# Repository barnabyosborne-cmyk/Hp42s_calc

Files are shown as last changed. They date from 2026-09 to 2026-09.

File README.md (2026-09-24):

# HP-42S clone — Plus42 on an ESP32-S3

An HP-42S-shaped calculator: e-paper display, LiPo cell, USB-C and BLE, a
custom keypad PCB with metal dome switches, a resin-printed case, running
[Plus42](https://thomasokken.com/plus42/) on an ESP32-S3.

Case dimensions follow the original HP-42S as closely as the parts allow:
**148 × 80 × 15 mm**.

## What is in here

| Path | What it is |
|---|---|
| `elec/src/*.ato` | The wiring, as [atopile](https://atopile.io) source. Compiles to a netlist. |
| `elec/footprints/hp42s.pretty/` | The footprints KiCad does not ship, generated by the two scripts in `tools/`. |
| `elec/layout/` | The KiCad project. Placement and routing live here. |
| `tools/gen_dome_footprints.py` | Parametric generator for the metal dome sites. |
| `tools/gen_ic_footprints.py` | The same for the regulator, the IR emitter, the status LED, the ESD array, the USB-C receptacle and the recovery buttons. |
| `docs/connections.md` | The connection table in prose, with the reasoning. |
| `docs/keypad-geometry.md` | The measured key grid, and the clearances that follow. |
| `docs/display-mounting.md` | The panel's tail and off-centre image, and where the cell can go. |
| `docs/front-face.md` | The etched metal plate, the window, and an edge-lit frontlight. |
| `docs/before-layout.md` | **What is still open, and whether it stops you starting.** |
| `docs/board-thickness.md` | Why the board is 1.6 mm, and flex under the keyboard. |
| `docs/layout-walkthrough.md` | **The layout, step by step.** Written for a first PCB. |
| `docs/pcb-process.md` | The map from netlist to boards in your hand. |
| `docs/kicad-setup.md` | Why the pin numbers are what they are. |
| `docs/breadboard.md` | What a XIAO ESP32-S3 and a spare Waveshare panel can and cannot prove. |
| `firmware/` | The Plus42 port. Not started. |
| `hardware/` | Case and keycap files. Barnaby's own CAD. |

## Building the netlist

```
pip install atopile        # 0.2.69 at time of writing
ato --non-interactive build
```

The flag goes before `build`, not after.

Output lands in `build/`: `default.net` (KiCad netlist), `default.csv` (BOM),
and a designator map. atopile does the wiring and the netlist; it does **not**
place or route. Layout stays in KiCad.

## Headline choices

- **MCU** — ESP32-S3-MINI-1-N8. The S3 over the C3/C6 because only the S3 has
  full USB OTG, which is what allows drag-and-drop file transfer as a mass
  storage device. The `-N8` specifically: it has no PSRAM, and octal PSRAM
  would eat GPIO33–37, where the panel interface lives.
- **Display** — Good Display GDEY0266T90, 2.66", 296 × 152 px in a 71.82 ×
  36.30 mm outline. Plus42 character cells are 6 × 8 px, rendered **2× across
  and 3× down**, giving **24 columns × 6 rows** at very close to the original
  42S's character size. The obvious 2.9" panel is 79.0 mm wide and will not
  fit an 80 mm shell. See `docs/character-size.md` for why the scaling is not
  square.
- **Power** — BQ25185 charger with power path → TPS63900 buck-boost to 3.3 V →
  MAX17048 fuel gauge. The buck-boost is mandatory: the panel's VCI cannot
  take 4.2 V.
- **Keypad** — 37 keys, 6 columns × 7 rows, no diodes. Columns sit on
  RTC-capable GPIOs and wake the chip from deep sleep via `ext1`, so there is
  no scanner IC and no standing current. The physical grid is measured off a
  real 42S and is not uniform: 12.5 mm columns on the function rows, 15 mm
  across the numeric block.
- **On and off are keys, not a switch.** `EXIT/ON` wakes it and shift-`EXIT`
  sleeps it, the way a real 42S works. There is no power slider: the 3.3 V rail
  is always up and "off" is deep sleep at about 21 µA. Driving row 6 alone and
  arming `ext1` on column 0 alone makes `EXIT/ON` the only key that can wake it.
  `docs/power-control.md`.
- **Single-sided assembly.** Every part the fab house solders is on the back of
  the board. The front carries the panel, the 38 dome sites and the frontlight
  sliver's lands, all fitted afterwards. `docs/top-edge.md`.
- **Battery life** — roughly **15 months** on the 1600 mAh cell that fits, at
  2 h/day and 1500 keystrokes. About 33 hours of continuous execution. The cell
  is 6 × 45 × 55 mm, in board X 14–69 and Y 13–58 on the back.

## What is not settled

- **The panel's 47 µH inductor.** Named (Sumida CDRH2D18) but still on a
  stand-in land pattern, because the drawing has not turned up.

## Licence

The Plus42 firmware is GPLv2, and that carries over: anyone given or sold a
unit has to be able to get the source. Worth deciding on before the firmware
lands here.

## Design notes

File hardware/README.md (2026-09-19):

# Hardware — case and keycaps

Barnaby's own CAD. Nothing generated here.

Constraints the electronics impose:

- Case **148 × 80 × 15 mm**, board about **144 × 76 mm**, 4 layer.
- Face budget, from Barnaby's measurements of a real 42S rather than a
  reconstruction: the keyboard area is **70 × 78 mm**, its datum 5 mm in from
  the left and 9 mm up from the bottom. That leaves **61 mm** above it for the
  bezel and display, and a **9 mm chin** below.
- Key pitch: rows **12.0 mm** throughout; columns **12.5 mm** on rows 1–3 and
  **15.0 mm** on the numeric block of rows 4–7, with the left column staying
  on the 8.75 mm centre. Full table in `docs/keypad-geometry.md`.
- Keycaps 6.0 mm tall: 7.5 mm wide on rows 1–3 and in the left column,
  10 mm wide on the numeric block, and ENTER 20 mm wide.
- Keycap actuator must be **≤ 25 % of dome diameter**, centred. That is a
  Snaptron rule and it is why the centre pad in the footprint is small.
- Battery bay behind the keyboard: one clean **50 × 60 mm** rectangle, 5 mm
  deep, ≥ 15 mm clear of the module antenna.
- Panel mounts on the front of the board; its tail folds through a slot to a
  connector on the back, so the connector height stays out of the front stack.

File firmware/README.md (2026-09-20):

# Firmware — porting Plus42

The **board layer and the Plus42 core both build for the ESP32-S3.** Plus42
1.3.15 (Thomas Okken, GPLv2) is vendored in `components/plus42core/`, its
decimal arithmetic comes from Intel's BID library in `components/libbid/`, and
`main/shell.cc` is the platform layer that joins them to the board. What is
**not** done yet is the rest of the shell: keys are not yet fed to the core,
the annunciator strip is a stub, and nothing saves state. The display blitter
is written -- it scales 2x across and 3x down into the 275-pixel strip the
case aperture leaves visible, giving 23 columns by 6 rows -- but it has never
driven real glass.

## What is here

| File | What it does |
|---|---|
| `main/board.h` | Every pin number, in one place. The only file that changes for a different board. |
| `main/epd.c` | SSD1680 driver for the GDEY0266T90: init, full update, partial update, deep sleep. Landscape 296 x 152. |
| `main/keypad.c` | 6 x 7 diodeless scan, debounce, and `ext1` wake on any column going low. |
| `main/shell.cc` | The 22 shell functions Plus42 asks the platform for. Real: the display blitter, with 2x/3x scaling into the visible window, milliseconds, random seed, log. Stubbed: beeper, printer, clock, power-down. |
| `main/main.c` | Bring-up app. Draws a test pattern, starts the core, echoes key presses, deep-sleeps after 10 s idle. |
| `components/plus42core/` | Plus42's portable core, unmodified, plus a CMakeLists. |
| `components/libbid/` | Intel's decimal library. Sources are laid out by `vendor/setup.sh`, not committed. |

## Building

```
cd firmware
./vendor/setup.sh
. $IDF_PATH/export.sh
idf.py set-target esp32s3
idf.py build
idf.py -p /dev/ttyACM0 flash monitor
```

Built against ESP-IDF v5.5 on 2026-09-19.

## What it costs

Measured, at `-Os`, with the whole core linked in:

| | Flash | RAM |
|---|---|---|
| Intel decimal library | 2.20 MB (2.06 MB of it lookup tables) | 34 KB |
| Plus42 core | 414 KB | 6.7 KB |
| Board layer | 3 KB | 11 KB |
| **Whole image** | **2.85 MB** | **113 KB of 334 KB** |

So the `-N8` module's 8 MB of flash is comfortable but not generous: the app
gets a 4 MB partition (`partitions.csv`), leaving 3 MB of FAT for programs and
state. 221 KB of RAM is left for Plus42's heap, which is where user programs,
variables and the stack live.

**The decimal tables are the whole story on flash.** Free42 and Plus42 also
build in a "binary" flavour that uses the hardware double instead, which would
drop about 2 MB. It would also stop the calculator rounding the way a real 42S
rounds, so it is not on the table unless flash becomes the binding constraint.

## Three things that had to be worked out

1. **Exceptions.** The core throws in three places (`core_equations.cc`,
   `core_display.cc`, `core_commands9.cc`), so `CONFIG_COMPILER_CXX_EXCEPTIONS`
   has to be on. That costs 39 KB of unwind tables.
2. **`fexcept_t`.** Intel's header defines it as `unsigned short` unless a
   `fenv.h` guard macro is already set, while newlib's is `unsigned long`; the
   two collide. Both components are compiled with `-include fenv.h` so
   newlib's definition wins everywhere.
3. **`shell_always_on()` and `shell_alpha_keyboard_enabled()`** look like
   shell functions but are not: the core defines the first itself off Android
   and iOS, and `shell.h` macro-defines the second. Supplying either is a
   link error.

## The shell API

About 22 functions the platform has to supply. The ones that carry real work:

- `shell_blitter` — the whole display. **Must not assume a fixed size.**
  Plus42 resizes the display at runtime (`ROW±`, `COL±`, `SETDS`, `WIDTH`,
  `HEIGHT` in the DISP menu), 2–99 rows and 22–999 columns. Cells are 6 × 8 px.
  It also scales **anisotropically**: 2× across, 3× down, so one logical pixel
  becomes a 2 × 3 block of panel pixels. That is not something to tidy up later
  — it is what makes the characters the size of a real 42S's, because the
  original's pixels were 0.42 × 0.65 mm and ours are square. Two constants
  stand between 24 × 6 and 24 × 9. See `../docs/character-size.md`.
- `shell_annunciators` — the status strip.
- `shell_request_timeout3`, `shell_delay`, `shell_milliseconds` — timing.
- `shell_read_saved_state` / `shell_write_saved_state` — state to flash.
- `shell_get_mem`, `shell_low_battery`, `shell_powerdown`.
- `shell_print`, `shell_write`, `shell_read` — printing and file transfer.
- `shell_get_acceleration` / `_location` / `_heading` — stub these out.

## Power state machine

Three states, and two rules that matter more than the rest:

| State | Trigger | Cell current |
|---|---|---|
| Active | key or timer | ~24 mA |
| Idle | 0.5 s quiet, light sleep (SRAM retained) | ~265 µA |
| Off | 5 min quiet, deep sleep, state flushed to flash | ~25 µA |

1. **Never deep-sleep with a core timeout pending.** `core_keytimeout1` fires
   at 0.25 s and `core_keytimeout2` 2 s later; losing them loses keystrokes.
2. **Light-sleep through the panel refresh, waking on BUSY.** Spinning through
   a 400 ms partial update instead costs about 5× the energy per keystroke —
   0.70 µAh becomes 3.8 µAh. This one decision is the difference between
   15 months and 3.

A naive always-active port gets about 40 hours.

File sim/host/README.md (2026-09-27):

# Plus42 on a PC, drawing the real panel layout

`hp42s_host` is Plus42 and `firmware/main/shell.cc` compiled for this
computer, with a stand-in for `epd.c` that keeps the same framebuffer layout
and saves every panel update as a picture. It shows what the calculator draws
and where `shell_blitter` puts it on the 296 x 152 panel, including the columns
the case hides (grey) and the annunciator strip along the bottom.

It does not test the keypad scan or the SSD1680 protocol; that is what
`sim/wokwi/` is for. It costs no Wokwi minutes and runs in about a second.

```bash
bash ../../firmware/vendor/setup.sh      # once: lays out Intel's decimal library
make                                     # builds /tmp/hp42s-host/hp42s_host
make frames KEYS="2 ENTER 3 ADD SQRT"    # PNGs and sheet.png in /tmp/hp42s-host/frames
```

Keys are named by their legend in `host_main.cc` (`SHIFT`, `ENTER`, `ADD`,
`SIN`, `7`, ...) or given as core key numbers 1 to 37. It prints the X
register after each key, and the frame each key produced.

`frames.py` also reads a Wokwi run's output: `python3 frames.py run.log DIR`.

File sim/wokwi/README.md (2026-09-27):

# Wokwi simulation of the keypad and panel

Work in progress. What is here and what is left, so the next session can pick
it up.

## Done

- `chips/ssd1680.chip.c` -- a Wokwi custom chip for the SSD1680: SPI command
  and data decoding, RAM with address counters (0x11, 0x44/0x45, 0x4E/0x4F),
  BUSY timing (attributes `fullUpdateMs`, `partialUpdateMs`), hardware reset,
  deep sleep. Draws the black/white RAM landscape, 296 x 152. Warns on the
  console about commands sent while BUSY or during deep sleep, and RAM writes
  outside the window. **Builds** with `make -C chips` (clang wasm32 +
  wasi-libc + libclang-rt-18-dev-wasm32); not yet run in Wokwi.
- `firmware/` -- an ESP-IDF app that links `firmware/main/keypad.c` and
  `epd.c` unmodified and prints `key <n> <name>` / `up <n>` per keypress.
  Built with `HP42S_WOKWI`, which moves the panel's CS and DC to GPIO 40 and
  42 (`board.h`), since the DevKitC-1 does not bring out 33 and 34. **Not yet
  compiled.**

- `diagram.json` and `keypad.test.yaml` -- generated by `gen_diagram.py` from
  `s_map` in `keypad.c`, the pins in `board.h` and the legends in `sim_main.c`,
  so they cannot drift from the code. Re-run it after any of those change.
- `wokwi.toml` -- points wokwi-cli at the IDF build and the chip.

**2026-09-27: all 37 keys pass.** Each press prints the right key number and
legend, each release prints `up`, and the SSD1680 chip sees a clean full
update at start then one partial per key, with no command sent while BUSY.

## Running it

The IDF build cannot run inside `/mnt/project-files`, so copy the sources out:

    mkdir -p /tmp/sim && (cd /mnt/project-files/hp42s && tar cf - firmware/main sim) | tar xf - -C /tmp/sim
    cd /tmp/sim/sim/wokwi
    make -C chips                      # needs wasi-libc, libclang-rt-18-dev-wasm32
    (cd firmware && idf.py set-target esp32s3 build)
    wokwi-cli --timeout 240000 --scenario keypad.test.yaml .

`WOKWI_CLI_TOKEN` must be set. A full run takes about two minutes of
simulated panel refreshes. Set the chip's `debug` attribute to `"1"` in
`diagram.json` to log every SSD1680 command.

`wokwi-cli --screenshot-part` does not work on a custom chip ("Part does not
have a valid framebuffer"), so the panel image is only visible in the VS Code
extension or on wokwi.com.

## The calculator: `calc/`

`calc/` is Plus42 itself in the simulator: the real `shell.cc`, `keypad.c` and
`epd.c` under `calc/main/calc_main.c`, which prints `x <value>` after every key.
The panel chip in `calc/diagram.json` has `dumpFrames` on, so each frame it
shows is printed as `EPDFRAME` lines. `gen_diagram.py` writes both diagrams.

```bash
cd sim/wokwi/calc
idf.py set-target esp32s3 && idf.py build     # needs ../../../firmware/vendor/setup.sh run once
wokwi-cli --timeout 300000 --scenario add.test.yaml . | tee run.log
python3 ../../host/frames.py run.log frames/   # one PNG per frame, plus sheet.png
```

`add.test.yaml` presses 2 ENTER 3 + and waits for `x 5`. It builds (3.1 MB,
26% of the app partition free). It **has not run in Wokwi yet**: on
27 September 2026 the account's free monthly CI minutes were used up.

For what the screen looks like without spending Wokwi minutes, `sim/host/`
runs the same core and `shell.cc` on a PC.

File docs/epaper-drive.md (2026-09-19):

# Driving the e-paper panel

## Is there a driver board as well as the panel?

No, and yes.

There is no driver *board*. The controller for the GDEY0266T90 is an SSD1680
bonded directly to the panel's own glass, under the black strip at the edge of
the tail. You cannot buy it separately and you cannot design it out. When you
see a Good Display "driver board" — the DESPI-C02 and its relatives — you are
looking at a carrier that holds an FPC connector, a level shifter you do not
need, and the circuit below. It exists so that a panel can be plugged into an
Arduino. We are not plugging into an Arduino.

There is a driver *circuit*, and it was missing. It is now in
`elec/src/display.ato`. Eighteen parts.

## Why the panel needs anything at all

Electrophoretic ink moves when you push it with about +22 V and pull it with
about -20 V. The SSD1680 generates both rails itself, but it has no inductor
and no power switch on the glass, so it reaches outside for them through two
pins on the tail:

| pin | name | direction | what it does |
|-----|---|---|---|
| 2 | GDR | out | gate drive. The controller switches the external FET with this. |
| 3 | RESE | in | current sense. The voltage across R2 tells it how hard the inductor is being driven. |

The regulation loop is closed inside the panel. No MCU pin goes near it and
there is nothing for the firmware to do beyond the ordinary SSD1680 power-on
sequence. When the controller is asleep it stops driving GDR, the 1 M pulldown
holds the gate off, and the whole network draws nothing.

## The circuit

One switching node does both rails, which is why the parts count is so low.

    3V3 --+-- L1 47uH --+-------------------- D3 >|-- PREVGH --> VGH (pin 21)
          |             |                                |
         C4            Q1 drain                         C5
        4u7            Q1 gate <-- GDR (pin 2)          1u
          |            Q1 source --> RESE (pin 3)        |
         GND            |           |                   GND
                       R1 1M       R2 2R2
                        |           |
                       GND         GND

                        |
    switching node -----+-- C3 4u7 --+-- D2 >|-- GND
                                     |
                                     +-- |< D1 -- PREVGL --> VGL (pin 23)
                                                      |
                                                     C11 1u
                                                      |
                                                     GND

D3 is an ordinary boost diode and makes the positive rail. D1, D2 and C3 are a
charge pump hanging off the same node and make the negative one: D2 clamps the
pump node to ground on the up-swing, and on the down-swing the node goes below
ground and drags charge off VGL through D1.

Then ten capacitors, all 1 uF/25 V unless noted, all straight to ground:

| on | panel pin | Good Display ref |
|----|---|---|
| VCI (also 3V3) | 16 | C6 |
| VDD | 18 | C7 |
| VSH1 | 20 | C9 |
| VSH2 | 5 | C2 |
| VSL | 22 | C10 |
| VGH / PREVGH | 21 | C5 |
| VGL / PREVGL | 23 | C11 |
| VCOM | 24 | C12 |
| 3V3 input, 4.7 uF | — | C4 |
| pump, 4.7 uF | — | C3 |

The 25 V rating is not optional. VGH sits near +22 V and a 16 V part there
fails. Nor is it free: a 25 V X5R in 0603 loses most of its capacitance under
bias, which is why these are 0603 and not 0402 like everything else on the
board.

VDD (pin 18) is the controller's *own* internal regulator output. It takes a
capacitor and nothing else. Driving it kills the panel.

BS (pin 8) goes hard to ground, which selects 4-wire SPI. Pins 1, 4 and 19 are
no-connects; 6 and 7 are the touch I2C on the touch version of this glass and
ours has none.

## Where these numbers come from

Good Display's *GDEY0266T90 Specification*, revision 24.12.03, page 28. Not
from a generic SSD1680 application note: the inductor and the pump caps differ
between panels that share this controller, and a 2.13 inch reference circuit
will not drive this one properly.

Their spare-parts table, which is the actual purchasing spec:

    C1-C12   0603/0805, X5R/X7R, >= 25 V
    R1, R2   0603/0805, 1%, >= 0.05 W
    D1-D3    MBR0530: >= 30 V reverse, >= 500 mA, Vf <= 430 mV
    Q1       Si1304BDL / NX3008NBK: BVdss >= 30 V, Vgs(th) 0.9 V typ,
             Rds(on) <= 2.1 Ohm at Vgs = 2.5 V
    L1       Sumida CDRH2D18 or LDNP-470NC, 47 uH, Io = 500 mA max
    P1       24 pins, 0.5 mm pitch

**The MBR0530 is discontinued**, so D1-D3 are `1N5819HW`: 40 V, 1 A, same
SOD-123 outline, stocked everywhere. The 430 mV forward limit is Solomon's
number at their 500 mA sizing current; this pump draws tens of milliamps,
where a 1N5819HW sits well under it. The one thing to keep an eye on is
reverse leakage, because a charge pump holds its rail rather than being fed
one, and Schottky leakage is what drains VGH between refreshes. Nexperia's
PMEG family is the better class of part if a SOD-123 one can be sourced.

**Q1 is the Si1308EDL**, not either part Solomon name, and it beats the spec
they set: 30 V, Rds(on) 0.185 Ohm max at Vgs = 2.5 V against their 2.1 Ohm
limit (Vishay document 63399 rev C). Its package is **SOT-323 / SC-70**, not
the SC-75A this repo had it as.

Q1's low gate threshold is the reason it is not the 2N7002 used elsewhere on
this board: the panel drives that gate from its own 3.3 V logic, and a 2N7002
is only specified to turn on by 2.5 V.

## Layout notes

The switching node — L1, Q1's drain, C3 and D3's anode — is the only fast node
on the board other than the buck-boost. Keep that loop small and keep it away
from the panel's SPI, which runs alongside it into the same connector.

R2 carries the switched current, so it wants a short path to the ground pour,
and its 1% tolerance is real: the panel sets its peak inductor current from the
voltage across it.

L1 in an NR3015 body is 1.5 mm tall, which makes it the tallest part on the
board after the module and the cell.

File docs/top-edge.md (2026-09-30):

# The top edge

Five things come out of the 80 x 15 mm top face of the case, and all five are on
the **back** of the board:

| | part | why it is here |
|---|---|---|
| IR emitter | Vishay VSMB2943SLX01, 940 nm side-looking | the original 42S's IR window is on this edge |
| USB-C | GCT USB4105-GF-A | charging and file transfer |
| status LED | Dialight 599-0Q70-247F, red/green side-view | boot, error, nominal |
| BOOT | Alps SKRTLAE010, side push with guide bosses | recovery |
| RESET | Alps SKRTLAE010, side push with guide bosses | recovery |

**There used to be a sixth, a C&K JS102011SAQN power slider.** It went on
24 September 2026: a real HP-42S switches on with a key, and so does this one.
`docs/power-control.md` has the whole of that change. It freed board X 6 to 16
on this edge and nothing has claimed it.

## Why the back

Barnaby asked on 24 September 2026 to put them on the back, "more balanced for
the centering of them in the top panel". He is right, and the stack-up says by
how much.

`docs/front-face.md` sets the vertical budget: a 15 mm case with 1.2 mm shells
leaves 12.6 mm inside. Measured from the case's outer **front** surface, with
the light guide against the inside of the front shell:

| | from | to |
|---|---|---|
| front shell | 0.00 | 1.20 |
| light guide, 1.0 mm cast acrylic | 1.20 | 2.20 |
| air gap | 2.20 | 3.00 |
| adhesive | 3.00 | 3.20 |
| panel glass | 3.20 | 4.20 |
| **board, 1.6 mm** | **4.20** | **5.80** |
| cell, 6 mm | 5.80 | 11.80 |
| slack | 11.80 | 13.80 |
| back shell | 13.80 | 15.00 |

So the board's front face sits 4.20 mm inside the case and its back face 5.80.
The top wall's centreline is at 7.50. Each part's aperture is on the axis of
whatever comes out of it, and that axis is a fixed height above the face the part
is soldered to — measured off the vendor STEP models in
`elec/footprints/hp42s.3dshapes`:

| part | axis above its own face | on the FRONT | on the BACK | off centre, front / back |
|---|---|---|---|---|
| USB-C mouth | 1.28 | 2.92 | **7.08** | 4.58 / 0.42 |
| IR optical axis | 1.15 | 3.05 | **6.95** | 4.45 / 0.55 |
| tact plunger | 1.65 | 2.55 | **7.45** | 4.95 / 0.05 |
| status LED lens | 0.50 | 3.70 | **6.30** | 3.80 / 1.20 |

On the back all four apertures land within 1.2 mm of the wall's centreline, and
the two mechanical ones within half a millimetre. On the front they sat 4 to 5 mm
high in a 15 mm wall.

**And the USB-C one was not merely off centre, it did not fit.** With the
receptacle on the front, the top of its 2.56 mm shell is at 1.64 mm — which is
0.44 mm short of the front shell's inner face at 1.20. That is a 0.44 mm ledge of
resin over the cut-out, which is not a printable feature. Worse, the plug: a
Type-C plug's overmould is about 4.5 mm across, so centred on a mouth 2.92 mm
below the outer surface it would stand about half a millimetre **outside** the
case's front face. The receptacle could have been soldered; the cable could not
have been plugged in without slotting the front of the case.

On the back the same plug body spans 4.8 to 9.3 mm, with 3.6 mm of clearance to
the front shell and 4.5 mm to the back one.

### What it costs

**3.5 mm of battery bay, and then 1 mm of cell thickness.** Two steps, and the
second is the one Barnaby's case model has to absorb.

The bay was board Y 5 to 59, about 54 mm, and it took a 5 x 50 x 60 mm cell —
1600 mAh with a millimetre to spare. The five parts on the back reach as far in
as the USB-C's courtyard at Y 7.24, so the bay would start at Y 8.5: 50.5 mm,
which the same cell still fits, with nothing to spare.

Then Barnaby asked for every reflowed part on one side (below), which put the
nine parts that serve the top edge on the back as well. The deepest of those is
U1 at Y 11.66, so **the bay is now Y 13 to 58, 45 mm, X 14 to 69.**

A 6 x 45 x 55 mm cell is about 14,850 mm³ against the 505060's 15,000, so it is
**the same 1600 mAh one millimetre thicker**, and it was always the second of the
three fallbacks in `docs/display-mounting.md`. The 6 mm is already in the table
above: `docs/front-face.md` budgeted a 6 mm cell from the start and the deepest
arrangement still leaves 2.0 mm of slack. Nothing has to grow.

If a 6 mm cell in that footprint turns out to be hard to buy, the other two
fallbacks are unchanged and both still work: let the cell run past Y 58 into the
keyboard region, or accept about 1400 mAh in 5 x 48 x 55.

### What it gives back

**The USB-C's four through-hole shield fillets are on the FRONT now.** They used
to land in the battery bay at board Y 0 to 5, under the cell, which is why the
bay was 54 mm and not 57 — a pouch cell resting on four solder fillets is not a
risk worth taking, because the case is soft aluminium laminate and it grows over
its life. Those fillets now come through under the bezel, where nothing touches
them.

One thing to check against the case model: keep the frontlight's light guide
clear of board Y 0 to 5, or let it stop at the glass. There is 3.0 mm of air in
front of the board in the bezel band and a through-hole lead cut for a 1.6 mm
board stands well under that, but the guide is the only part that could foul it.

## Everything the fab house solders is on the back

Barnaby asked for this on 24 September 2026, to make the board a single-sided
assembly. It is the cheaper build: one stencil, one paste print, one reflow, no
glue and no second pass.

**The front now carries nothing that comes back from the fab already soldered.**
What is on the front is the panel, the 38 dome sites and the frontlight sliver's
two lands and ground point, all of which go on afterwards.

What moved with it, from the front at exactly the same x and y:

| | serves |
|---|---|
| U1, R1, R2, C1 | the USB-C: ESD array, CC pulldowns, VBUS bulk cap |
| Q2, R17, R18 | the IR emitter's driver |
| R19, R20 | the status LED's two ballast resistors |

They are all directly behind where they were, so every distance to the part it
serves is unchanged, and the USB pair no longer has to cross the board through
vias to reach its ESD array. `tools/check_placement.py` reports the whole board
clear at 1 mm courtyard to courtyard.

Turning a footprint over mirrors it in y, so pin 1 of U1 and of Q2 has moved from
one end of the body to the other. Neither matters — the ESD array's four channels
are interchangeable and the SOT-23 is a single transistor — and nothing is routed
yet.

**One thing still spoils the single-sided story, and it is worth a look now.**
This USB-C receptacle anchors with four through-hole shield legs. Every 16-pin
Type-C part does; they take the cable strain, which is why the case gets a lip
rather than the connector getting a different land pattern. But a through-hole
part is a second operation whichever side it protrudes from. A receptacle with
**SMD-only shell tabs** would make this board genuinely one-pass. The two
locating pegs and the Alps switches' guide bosses are non-plated holes and cost
nothing. `BT1` is already on its way from a through-hole JST PH to the SMD
`S2B-PH-SM4-TB`.

## Side actuation is the whole trick

An ordinary tact switch has its plunger on top, pointing out of the board's face.
It cannot reach a case edge. Both switches here are side-actuated: the plunger
comes out of the *end* of the body, in the plane of the board.

- **Reset and BOOT: Alps SKRTLAE010**, body 4.5 x 2.56 mm with the plunger
  **1.05 mm** proud of it (0.84 was the catalogue figure; Alps' own STEP model,
  checked 23 September 2026, has it reaching 2.261 mm from the origin),
  4.5 x 3.55 overall and 3.3 tall, with the guide bosses 0.5 below the board
  face. 1.6 N to operate and 0.2 mm of travel, so it is a deliberate press with
  a fingernail or a pen, not something a pocket does by accident. 100,000
  cycles, which for these two is forever.

  It is the `-LAE010`, the variant **with guide bosses**, so each one needs two
  0.9 mm non-plated holes in the board as well as its five pads, and a 2.0 x
  1.2 mm patch between the mounting pads that Alps marks as prohibited for
  copper. All three are in the footprint. The `-LBE010` is the same switch with
  no bosses and no holes if that ever becomes awkward.
- **USB-C: GCT USB4105-GF-A**, mouth flush with the board edge. Shell outside
  8.64 x 2.56 mm, body 8.94 wide x 7.35 deep, with four through-hole shell legs
  and two 0.65 mm locating pegs. KiCad's footprint is drawn from GCT's own
  document and marks the product edge on Dwgs.User at 3.675 mm from the origin,
  which is what the placement is set from — the same number the Same Sky UJ20 it
  replaced on 22 September 2026 used, so the case cut-out line did not move.

  **A Same Sky UJC-HP-G-5-SMT-TR was evaluated on 24 September 2026 and
  rejected: it is power-only.** It has six contacts — A5/B5 `CC`, A9/B9 `VBUS`,
  A12/B12 `GND` — and no `D+`/`D-` at all. That is a fine part for a charge-only
  product and it is a smaller one, 11.54 x 7.14 x 3.21 mm from its STEP model,
  but this board needs USB **data** twice over. Once because file transfer over
  USB is a headline feature, the thing you plug in to load a program. And once
  because the S3's own USB peripheral is the only flashing path that exists
  here: there is no USB-UART bridge on the board (see "Why a BOOT button as well
  as RESET" below), so with a power-only receptacle a bricked board could not be
  reflashed at all, by anyone, ever. Keep the USB4105-GF-A.

## Reset

A plain button from the module's `EN` to ground. It is a hardware reset of the
chip and does not go near the firmware, which is the only reason to have it — you
press it when the firmware has stopped working. With no power slider it is also
the only way to interrupt firmware that has hung: see `docs/power-control.md`.

The existing 10k and 1 uF on `EN` debounce it for free: the cap holds `EN` down
for about 10 ms after release, and Alps specifies the contact bounce at 10 ms
when new and 20 ms at end of life. Those are the same order, so the RC does not
swallow the bounce outright — what it does is turn a bounce train into one slow
ramp, because the cap cannot recharge through 10k faster than the contacts are
chattering. The chip sees one release. `BOOT` is the one that needs the software
debounce: 20 ms or more, from the same Alps number.

Recess it in the case. This is not a key. A reset button you can press while
holding the calculator is a reset button you will press while holding the
calculator.

## Why a BOOT button as well as RESET

Because it is the only recovery path, and without it the recovery path is a
screwdriver.

A dev board gets away without a BOOT button because its USB-UART bridge wiggles
`EN` and `IO0` from the host, which is how esptool puts the chip into download
mode on its own. This board has no bridge — the S3 drives USB itself. The moment
the firmware claims the USB OTG peripheral for mass storage, the USB-Serial/JTAG
path that esptool could otherwise reset through is no longer on those pins. And
if the firmware is broken enough not to enumerate at all, nothing on the host can
reach the chip by any route.

Hold BOOT, tap RESET, release BOOT, and the ROM bootloader comes up regardless of
what is in flash. Recess BOOT deeper than RESET; it is pressed roughly never, and
the two should not feel alike.

## The status LED

Dialight 599-0Q70-247F: two dice, red and yellow-green, sharing a **common
anode**, so a channel is driven LOW to light.

It is bi-colour, not RGB, and that is the right answer rather than a concession.
Red and green together read as amber, so two dice give three states, which is all
the indicator was ever asked for. A true RGB part would need a blue die, every
blue die is InGaN, and InGaN wants up to 3.9 V forward against this board's 3.3 V
rail. The 599's two AlGaInP dice run at 2.0 to 2.4 V with room to spare.
Barnaby's first pick, the -0Q40-, is yellow plus yellow-green, which no one can
tell apart through a diffused window; the -0Q70- is the same part with a red die
instead of the yellow.

Common anode does leave a weak pull-up on the two driving pins while they are
high impedance. That was a real objection when the plan was three channels on an
unverified part, and it is not one now: `IO16` and `IO39` are not strapping pins
— only `IO0`, `IO3`, `IO45` and `IO46` are — and the current through an unlit LED
is leakage rather than a divider. Dark at reset, through boot, and in deep sleep,
which is what matters: an indicator left on is milliamps against a 21 uA sleep
budget. Blink it during boot and on error, and leave it dark in normal use.

It costs two GPIOs rather than three. `IO16` was spare; `IO39` is one of the four
JTAG pins, which this board had already given up in practice — the USB pins go to
the OTG peripheral, and debugging runs over the UART0 test pads. **`IO40` goes
back to the free list**, and `docs/power-control.md` wants it: moving `LED_RED`
off `IO16` would free the S3's `XTAL_32K` pair for a real 32.768 kHz timebase.
1k on a 2.0 V die off 3.3 V is about 1.3 mA, plenty behind a case window.

**The lens is 1.0 mm tall and its axis sits 0.50 mm above the face it is
soldered to**, measured from Dialight's STEP model on 24 September 2026. This
file used to say "roughly 1.0 to 2.0 mm", which was a guess and was wrong. The
lens wants a diffused window rather than the clear one the IR needs.

## Placement

`tools/place_board.py` places all five, on the back. Y is depth from the board's
top edge, and each part is pushed out until its own pads stop it.

| part | x | y | courtyard across x | courtyard reaches | protrudes past the edge |
|---|---|---|---|---|---|
| IR emitter | 25.33 | 0.900 | 22.98 .. 27.68 | y = 2.34 | 0.73 mm |
| USB-C | 38.00 | 2.475 | 32.68 .. 43.32 | y = 7.23 | 1.70 mm |
| status LED | 50.57 | 1.050 | 48.32 .. 52.82 | y = 2.45 | 0.77 mm |
| BOOT | 60.65 | 1.800 | 57.82 .. 63.48 | y = 3.85 | 0.50 mm |
| RESET | 71.31 | 1.800 | 68.48 .. 74.14 | y = 3.85 | 0.50 mm |

**Two rules fix every x on this edge**, and they were applied on 24 September
2026 in place of the older hand-chosen numbers:

1. **The USB-C sits on the board's centreline.** The board is 76 mm wide, so
   `J1` is at x = 38.00 and the plug goes into the middle of the case's top
   face. That is the one number a user looks at, so it is the one that gets the
   symmetry.
2. **Every adjacent pair is 5.00 mm courtyard to courtyard.** Not centre to
   centre: these five parts are wildly different widths (the USB-C is
   10.64 mm across, the status LED 4.50 mm), so equal centre spacing would look
   crowded at the USB-C and empty at the LED. Equal *gaps* is what the eye
   reads as even, and it is also what matters for a stencil and for a fat
   thumb on a button.

The two indicators therefore straddle the USB-C — the IR emitter to its left,
the status LED to its right — and the status LED shares its side with the two
buttons, which is what Barnaby asked for: BOOT and RESET at 60.65 and 71.31,
each 5.00 mm clear of its neighbour.

What the rules cost: 22.98 mm of empty board left of the IR emitter, where the
slider used to be, and only **1.86 mm** right of RESET before the board edge.
That is the tightest number on the edge and it is the reason the chain cannot
grow: one more 5 mm gap and RESET would hang off the board. If anything else
ever has to go on this edge it displaces the chain leftwards, it does not
extend it.

X changed for all five when they were centred, so **any case hole drawn against
the old numbers moves**. The mapping itself is unchanged and does not depend on
which side a part is soldered to: `x_case = x_board + 2` either way. Depth in
the 15 mm wall also changed when they went to the back, by 4.16 mm.

**The rotations are not the front's rotations.** Turning a footprint over negates
every child y, so an actuator that pointed at -Y on the front points at +Y once
it is over: the 180 degrees comes off the USB-C and the two buttons rather than
going on. The two LEDs are the opposite — their lens faces are already the -y end
of the body, so they wanted 0 on the front and want 180 here. Get it wrong and
the IR beam and both plungers aim into the middle of the board.
`tools/check_placement.py` prints all five with their courtyards for exactly this
reason: every one must reach past y = 0.

**Both lenses are proud of the board edge, not inside it** — the IR dome by
0.45 mm and the status LED's lens by 0.475 mm, measured off the vendor STEP
models on 23 September 2026. The board is inset 2 mm from the case, so there is
room, but the case needs a relief pocket for each lens and not merely a window in
the wall: clear for the IR, diffused for the status LED.

## The IR emitter

Vishay VSMB2943SLX01, confirmed side-looking from document 83479 rev 1.2:
2.3 x 2.55 x 2.3 mm, 940 nm, 20 mW/sr, half angle +/- 25 degrees, 1.35 V typical
at 100 mA, 15 ns rise time. It is a far bigger part than the 1.6 x 0.6 mm pattern
that was standing in for it — two 0.9 x 1.2 mm pads 4.2 mm across the outsides —
so it has its own footprint, generated from Vishay's IPC 7351 solder pad proposal
by `tools/gen_ic_footprints.py`.

Two numbers for the case:

- The **optical axis sits 1.15 mm above the face of the board the part is
  soldered to**, from Vishay's own STEP model. It is on the back, so the beam
  runs 1.15 mm behind the back copper, at 6.95 mm from the case's outer front
  surface. **If you have already cut an IR window for the front, it moves.**
- The dome tip does not stop short of the board edge: it reaches 1.35 mm from the
  part's origin, and with D4 at board Y 0.900 that puts the tip at board
  **Y -0.45**, so it overhangs the edge by 0.45 mm. The lens is 1.8 mm across, so
  a 2.5 mm window centred on x = 25.33 clears the beam without vignetting the
  +/- 25 degrees — but the wall has to be relieved for the dome rather than
  merely windowed.

## Chamfered corners (30 September 2026)

Barnaby asked for 45° chamfers so the board clears the case's inside fillets:
**2 mm on the two top corners, 4 mm on the two bottom corners.** The outline is
now (2,0)–(74,0)–(76,2)–(76,140)–(72,144)–(4,144)–(0,140)–(0,2), with the FPC
notch on the left edge unchanged.

Only RESET (SW39) comes near a chamfer. Its right-hand mounting pad is 0.44 mm
from the top-right chamfer, inside the board's 0.25 mm copper-to-edge rule with
room to spare, and its courtyard just touches the cut line. Its body (fab
outline, X 69.06–73.56) stays clear of the cut, which starts at X 74. If the
case needs more room in that corner, the right-hand chain above can close its
5.00 mm gaps a little.

The bottom chamfers pass 2.5 mm from the SW33 and SW37 domes and about 2 mm
from mounting holes C and D. Nothing else on the board is within 3 mm of any
chamfer.

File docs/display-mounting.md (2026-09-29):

# Mounting the panel, and where the cell can go

Every number here is off Good Display's *GDEY0266T90 Specification* (rev
2021/10/12), mechanical drawing on page 5, except where it says otherwise.
Measure the physical panel before committing the board — the drawing gives the
tail length to ±0.3 mm and does not say unambiguously which edge of the glass
it is measured from.

**The Pi Hut's panel is the same panel.** Barnaby found a
`ZJY296152-0266EAAMFGN` (Zhengzhou Zhongjingyuan, spec rev 1.1, 16 Nov 2022)
he can buy locally, and it is a drop-in: SSD1680, 296 × 152, 30.704 × 60.088
active area, 36.30 × 71.82 × 1.0 glass, 14.30 mm tail, 12.50 mm wide, 0.30
thick, 24 contacts at 0.5 mm over an 11.50 mm span, and the same 24-pin
assignment from NC/GDR/RESE through to VCOM. The application circuit on its
page 28 is the same one in `elec/src/display.ato`, down to the 2.2 Ω sense
resistor, the MBR0530s, the Si1304BDL and the 47 µH inductor. Both are the
same OEM glass on the same `FPC-A003` flex, which is why the numbers agree to
the third decimal. Nothing on the board or in the firmware changes.

## The tail

| | |
|---|---|
| Glass | 71.82 × 36.30 × 1.0 mm |
| Tail length beyond the glass | **14.30 ± 0.3 mm** |
| Tail width | 12.50 ± 0.10 mm |
| Tail thickness | 0.30 ± 0.03 mm |
| Contacts | 24 at 0.5 mm pitch, 11.50 mm span, contact side 5.00 ± 0.50 mm |
| Where it exits | centred on one 36.30 mm edge: 11.90 + 12.50 + 11.90 = 36.30 |

**14.30 mm is the whole budget.** Mounted landscape on a 76 mm board the panel
leaves about 2 mm of board either side of it, so an unfolded tail ends roughly
12 mm off the left edge. It cannot reach a slot cut inside the board either:
a slot needs its own width plus a few millimetres of board outboard of it for
strength, and the panel is 71.82 mm wide on a 76 mm board. There is nowhere to
put one.

So the tail folds **around the board's left edge**, which is what Barnaby
proposed and is what every ESL tag using this panel does.

### Which face the contacts are on, and what it costs

**The contacts are on the panel's viewing face.** Two independent checks say
so. The `ZJY296152` drawing's side view labels *contact side* on the left-hand
face, which in third-angle projection — side view to the right of the front
view — is the front of the module. And Barnaby laid the physical panel face up
on 23 September 2026 and photographed it: the gold fingers are on top.

That settles the connector, and not the way the board was drawn. The panel
sits on the FRONT of the board with its viewing face pointing away from the
board, so its contacts point away from the board too. The half-turn around the
left edge carries that straight through: on the back they still face away from
the board. So the contacts present themselves to the **top** of whatever is
mounted there.

**The connector therefore has to be top contact.** It was a Hirose
FH12-24S-0.5SH, which is bottom contact — Hirose's own series page says
"0.5mm Pitch, Height 2.0mm Bottom Contact, Front Flip". A bottom-contact part
clamps the flex's board-facing side, which here is the bare backing. It would
have held the flex perfectly well and connected nothing.

It is now an **Amphenol F32Q-1A7H1-11024**: top contact, 0.5 mm pitch, 24 way,
2.00 mm high, 0.5 A, right-angle SMT ZIF. Same height as the FH12, 1.2 mm
shallower front to back. The **F32R** is the identical shell with bottom
contacts, so the letter matters when ordering.

There is no way to fold round this. A Z-fold before the edge would flip the
flex over, but the tail has 14.30 mm in it and the edge wrap already spends
3.30 of that; there is not another fold's worth left.

### The fold, with numbers

The two legs are separated in Z by the panel glass plus the board — about
2.1 mm — so the fold's natural radius is **about 1.05 mm** and the half-turn
eats 3.3 mm of tail. That leaves:

```
14.30  tail
-3.30  the half-turn (the panel's edge sits flush with the notched
------  board edge below, so there is no front leg to speak of)
11.00  back leg
```

Eleven millimetres of back leg, of which the last 4 mm sits inside the
connector. **So the FPC connector goes on the back with its pad row about 5 mm in from
the notched edge.** The connector body can extend as far right as it likes.

**2 mm of slack, 29 September 2026.** The connector first sat where the flex
ends pulled flat (back wall X 10.50), which gave the tail no give at all. It now
sits 2.00 mm nearer the edge, back wall X 8.50, so the tail's last 2 mm is
spare and forms a loose curve in the space under the board. That relieves the
strain on the connector and on the fold, and absorbs case tolerance. At the
tail's −0.3 mm tolerance there is still 1.7 mm of slack.

A 1.05 mm radius on a 0.3 mm FPC is tight — about 3.5× thickness. It is
normal practice for this class of part, but it is a fold you make **once**, on
assembly, not something that should flex in service. Two things help and both
are free:

- Route the board edge under the fold with a radius rather than leaving the
  square milled edge, and put a strip of Kapton over it. The failure mode is
  the board edge sawing through the FPC, not the bend itself.
- Do not let the case clamp the fold. The notch below gives it 0.3 mm of air
  to the case wall, and it should not get less.

## The panel is not centred on its own glass

This is the part that catches people. Across the long axis the active area sits
**8.93 mm from the tail edge and 2.80 mm from the far edge**. (Across the short
axis it is centred, 2.798 mm each side.) Centre the glass on the board and the
image lands 3.1 mm right of centre, which on a 60 mm image inside an 80 mm case
you would see every time you picked the thing up.

**Barnaby's decision, 2026-09-20: the image is what gets centred.** It cannot
be centred exactly, and it is worth understanding why, because the number that
comes out of it is one Barnaby controls in the case model rather than one this
board can fix.

### Why exactly centred is not available

For the image to be centred in an 80 mm case, its left edge has to sit
**9.956 mm** in from the case's outer face. Working from the outside in, three
things have to fit in that 9.956 mm and they do not:

```
  wall thickness             t
+ air for the fold        0.30
+ fold radius             1.05     half of (0.5 glass + 1.6 board)
+ the glass's own border  8.93     tail side
= where the image can start   t + 10.28
```

So the image ends up **(t + 0.32) mm right of centre** — near enough, off by
the thickness of the case wall. There is no arrangement that beats it. Putting
the tail on the right just mirrors the problem, and routing through a slot in
the board is worse, because a slot needs board outboard of it and that pushes
the panel further right still.

| case wall | panel left edge | board notch | image off centre |
|---|---|---|---|
| **1.2 mm** | **2.55 mm from the case face** | **0.55 mm** | **1.52 mm** |
| 1.5 mm | 2.85 | 0.85 | 1.82 mm |
| 2.0 mm | 3.35 | 1.35 | 2.32 mm |
| 2.5 mm | 3.85 | 1.85 | 2.82 mm |

**Barnaby's decision, 2026-09-20: the wall is 1.2 mm**, so the top row is the
one that is built. The wall thickness on that one side is the whole lever —
everything else in the sum is fixed by the panel and the board.

### Widening the case does not earn its keep

Barnaby offered to grow the case to 81 or 82 mm. It does help, at exactly
0.5 mm of centring per millimetre of case, because half the extra width lands
on each side while the left-hand stack stays put:

| case | image off centre | left bezel | right bezel |
|---|---|---|---|
| 80 mm | 1.52 mm | 11.48 | 8.43 |
| 81 mm | 1.02 mm | 11.48 | 9.43 |
| 82 mm | 0.52 mm | 11.48 | 10.43 |
| 83 mm | 0.02 mm | 11.48 | 11.43 |

So 83 mm would put the image dead centre. It would also stop the thing being
an HP-42S, which is the point of the project — the 148 × 80 × 15 mm case is a
decision made deliberately on 18 September and this is not a good enough
reason to reopen it. 1.5 mm is a real asymmetry but it is 1.5 mm.

**Barnaby's decision, 2026-09-20: the case stays 80 mm, and the aperture is
centred.** The image is masked in software to suit — see "The visible window"
below.

## The visible window

A centred aperture masks the panel unequally, because the active area is not
centred behind it. The widest centred aperture that stays inside the active
area is **57.04 mm**, against the active area's own 60.088 mm.

The firmware assumes **56.00 mm**, which runs case X 12.00 → 68.00 and leaves
0.52 mm of active area behind the case on the left and 3.57 mm on the right.
That is deliberately a millimetre inside the 57.04 limit: the left-hand margin
is the thin one, and if the aperture drifts left you start looking at the
panel's border rather than its ink.

In panel pixels that is columns **3 to 277** — 275 of 296, with 3 hidden on
the left and 18 on the right. `firmware/main/epd.h` carries it as
`EPD_VIEW_X` and `EPD_VIEW_W`, and `shell_blitter` drops anything that falls
outside rather than clipping it, so a glyph is either whole or absent.

**The cost is one character column**: 23 instead of 24, because 24 needs
286 pixels and we have 275. The original HP-42S showed 22, and Plus42's floor
is 22, so 23 is comfortable. Working in `docs/character-size.md`.

**Vertically nothing is lost.** The active area *is* centred on its own glass
across the short axis, 2.798 mm either side, so a centred aperture masks
nothing and all 152 rows survive.

If the aperture ends up a different width, the two constants in `epd.h` are
where it lives, and the column count follows from
`(cols × 6 − 1) × 2 ≤ EPD_VIEW_W`.

### The notch

The board is inset 2 mm from the case face all round, so with any wall of
1.35 mm or more **the board reaches the wall and there is nowhere for the fold
to go**. It needs a local notch in the board's left edge, `wall − 0.65` mm
deep, over about 16 mm of height centred on the panel. That is the cutout
Barnaby proposed, and this is the number for it.

The panel's left edge then sits flush with the notched board edge, the fold
wraps that edge, and the apex lands 0.3 mm clear of the case wall.

### Placement, as built

Board coordinates, X from the board's nominal left edge, Y down from its top.
`tools/place_keypad.py` now carries all of this and will draw it.

**Every Y moved 6 mm down on 21 September 2026**, when Barnaby chose a 14 mm
top bezel over the 8 mm this had been drawn at. Nothing in X changed, and
nothing about the fold or the centring changed — the panel simply sits lower
on the board. See `docs/top-edge.md`.

| | |
|---|---|
| Notch | X 0 → 0.55, Y 22.15 → 38.15 (16 mm, centred on the tail) |
| Glass | X 0.55 → 72.37, Y 12.00 → 48.30 |
| Active area | X 9.48 → 69.57, Y 14.80 → 45.50 |
| Image centre | X 39.52 against a board centre of 38.00 |
| Tail, unfolded | X −13.75 → 0.55, Y 23.90 → 36.40 |
| Fold apex | X −0.50, which is 0.30 mm clear of the case wall |
| Back leg ends | X 10.50 pulled flat; the connector takes it at X 8.50, leaving a 2.00 mm slack loop |
| FPC connector | origin X 7.75, Y 30.15, 270°, on the back, mouth facing the left edge |
| Connector body | X 5.50 → 8.50, courtyard X 3.80 → 10.50, Y 20.00 → 40.30 |
| Solder pad row | X 4.85, pin 1 at Y 24.40, pin 24 at Y 35.90 |

The connector is an Amphenol F32Q-1A7H1-11024. Its body is 3.00 mm deep, and
the back wall of that body goes at X 8.50, 2.00 mm short of where the flex
would end pulled flat, so the flex bottoms out against it with 2 mm to spare
and its own 3.00 mm of exposed finger fills the body exactly. Wherever inside
that body the contact point actually is, it is on copper. The solder pads
stand 0.65 mm proud of the mouth and land at X 4.85.

**Corrected 23 September 2026.** The board file had this at 90° rather than
270°, which is a single error that showed up twice: the mouth pointed right,
away from the fold, with the flex arriving at the closed end of the connector;
and the pin order ran backwards. Both are fixed by the one turn.

The pin order, from first principles: on the panel's own front view the tail
leaves the bottom edge with pin 1 at the left. Mounted landscape with the tail
to the left, that is a quarter turn clockwise, which puts pin 1 at the top of
the board. The fold is about the board's left edge, a vertical axis, so it
mirrors X and leaves Y alone. Pin 1 therefore arrives at Y 24.40 and pin 24 at
Y 35.90, which is what 270° gives.

The cost of turning it round is that the body runs right, towards the battery
bay. Since the 2 mm move it stops at X 10.50 (courtyard), which gives the cell
at X 14 more room than before. See below.

There is still 3.63 mm of board to the right of the glass, so nothing on that
side is tight.

### Which side the tail is on is a free choice

Rotating the panel 180° puts the tail on the right instead, and the firmware
absorbs it with a rotation in `epd_pixel()`. So pick whichever side suits the
case; nothing on the board depends on it. If it goes on the right, the 8.93 mm
border moves to the right and the image offset flips with it.

## Where this leaves the cell

**Settled 2026-09-21: the cell goes on the back**, at the top, which is where
Barnaby asked for it on 2026-09-20. The layout as drawn had it behind the
keyboard. What that costs is below, and the short version is that the top of
the back is currently the electronics bay, so the electronics move.

**Settled 2026-09-21: the bezel went to 14 mm**, which leaves 12 mm of board
above the panel. That is what made the top-edge parts placeable at all, and for
three days it put them on the front.

**Changed 2026-09-24: they are on the back again, and so is everything else the
fab house solders.** Barnaby asked for both — the parts centred in the top wall
rather than pressed against the case's front face, and a single-sided assembly.
The full argument, with the stack-up it comes from, is in `docs/top-edge.md`.
What it does to the cell is the section below.

**The ribbon can never reach the cell.** At 14.30 mm it is spent before it
clears the connector. So "short ribbon stopping before the battery" is not a
choice to make — it is the only thing the part can do. Which is just as well,
because running a 0.3 mm FPC under a pouch cell is a bad idea in any design:
the cell's case is soft aluminium laminate, it grows over its life, and the
board flexes. That is an abrasion path to an internal short, and an internal
short in a LiPo is a fire. Nothing goes under the cell.

### What actually fits up there

**As the board now stands, the bay is board X 14 to 69 and Y 13 to 58 — 55 x
45 mm — and the cell is 6 mm thick.** That is a 1600 mAh cell, the same capacity
as the 5 x 50 x 60 it replaces, and `docs/front-face.md` budgeted 6 mm from the
start, so the case does not grow. Three numbers for the case model, and all
three moved on 2026-09-24:

- **X 14**, not 10, because the FPC connector turned the right way round reaches
  X 12.50. That was already true on 23 September. X 69 rather than 74 is the new
  part: the cell is 55 mm wide now, not 60.
- **Y 13**, because every part the fab house solders is on the back and the
  deepest of them, U1, reaches Y 11.66.
- **45 mm tall**, from Y 13 to the keyboard line at 58.

The cell pocket is not centred on the board in either axis. `check_placement.py`
holds the same rectangle and fails if anything strays into it.

This is the second of the three fallbacks below, taken deliberately. It was
always the cheapest of them: same capacity, one millimetre of depth, and the
depth was already in the budget.

What follows was written when the top-edge parts were first on the back and the
bay was 49 mm. The arithmetic is the reason fallback 2 is what the board now
does:

A 1600 mAh cell at 5 mm thick is about 50 × 60 mm — a 505060. Turned on its
side it is 60 wide × 50 tall, and 50 does not fit in 49. It misses by a
millimetre, which is the kind of miss that eats a week.

Three ways out, in the order I would try them:

1. **Let the cell run past Y 59 into the keyboard region.** Nothing is on the
   back there — that is the whole reason the bay was put there in the first
   place. A cell sitting at Y 10–70 is still "at the top" in any sense that
   matters for balance, and it fits with room to spare.
2. **Go thicker rather than wider.** There are no keycaps above the display, so
   the back cavity at the top can be deeper than it can be behind the
   keyboard. A 6 mm cell in 45 × 55 mm is about the same 1600 mAh. Whether
   6 mm is there is a question for the case model, not for me.
3. **Accept about 1400 mAh** in a 5 × 48 × 55 cell. On the earlier estimate
   that is roughly 13 months rather than 15, which is not a real loss.

**Fallback 2 is what was taken, on 24 September 2026.** 1 and 3 are still open
if a 6 mm cell in 45 × 55 turns out to be hard to buy.

### What moving the cell up costs

The bay at the top of the back is currently the electronics bay: the FPC
connector, the panel's booster, the buck-boost, the charger and the fuel
gauge. Give it to the cell and all of that has to go behind the keyboard —
except the FPC connector and the panel's booster, which are pinned to the top
left by the tail length above and cannot move at all.

That is workable. The module's antenna has to overhang a board edge and the
bottom edge does that as well as the top. But it inverts the layout plan in
`docs/pcb-process.md`, and it means components behind the keys, which then
need a spacer so that pressing a key does not load them.

The one thing that gets **better**: the charger sits next to USB-C at the top
edge, and with the cell at the top the charge current no longer runs the
length of the board.

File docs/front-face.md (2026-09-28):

# The front face: metal plate, window, frontlight

Barnaby raised three things on 20 September 2026: a silk-screened thin metal
plate as the keyboard surround and display bezel, a window over the panel, and
— if the window were thick enough — edge-lit LEDs to make it a frontlight.

Short answers: **the plate is the best idea of the three and has a precedent**;
**a separate window is probably a mistake**; **the frontlight is real, and if
you build it the light guide becomes the window**, so the second and third
ideas collapse into one part.

The front stack-up is not the constraint on any of it. The 15 mm case with
1.2 mm shells leaves 12.6 mm inside, and the deepest arrangement — a 6 mm cell
at the top of the back, the board, the panel, its adhesive, a 1 mm light guide
and an air gap — comes to 10.6 mm. The keyboard side is looser still.

(That was 10.0 mm until 23 September 2026, when the board went from 1.0 mm to
1.6 mm to stop it flexing under the domes. It was this paragraph's 2.6 mm of
slack that paid for it. See `docs/board-thickness.md`.)

## The metal plate

This is how the DM42 is built, and how the Voyager series was built before it,
so it is a well-trodden path rather than an experiment.

**Process: photochemical etching, not laser cutting.** 0.5 mm stainless, etched
and then screen printed with epoxy ink. Etching gives a square, burr-free edge
and holds ±0.05 mm on a part this size; a laser leaves a heat-affected edge and
a taper you will see on a 0.5 mm sheet at reading distance. It is also the
cheaper process once there are 37 holes in the part.

The plate is strong enough easily. Allowing 0.25 mm of clearance round each
keycap:

| | hole | web to the next hole |
|---|---|---|
| function rows, 7.5 mm caps | 8.00 × 6.50 | 4.50 mm |
| numeric block, 10 mm caps | 10.50 × 6.50 | 4.50 mm |
| every row, vertically | | 5.50 mm |
| ENTER to `x↔y` | 20.50 × 6.50 | 3.25 mm |

3.25 mm is the tightest and that is still stiff in 0.5 mm stainless.

Three things follow that are not obvious:

- **The keycaps need a lip wider than their hole.** That is what retains them:
  the flange sits under the plate and the cap cannot fall out. Travel is the
  dome's 0.48–0.55 mm, so the flange wants about 1 mm of clearance beneath the
  plate before anything bottoms out.
- **Bond the plate to ground.** A metal plate the user touches is an ESD entry
  path straight onto the board. One bond, near the USB-C shield's ground
  stitch rather than near the module, gives the charge somewhere to go that is
  not through the MCU. A pad and a spring finger or a screw boss is enough.
- **~~It now has live parts underneath it at the top.~~ Not any more, as of
  24 September 2026: every part the fab house solders is on the BACK of the
  board, so there is nothing under the plate at the top but the USB-C's four
  through-hole shield fillets. Keep the light guide clear of board Y 0 to 5 and
  the question goes away. What follows was written when they were on the front
  and is kept in case they ever go back.** The six top-edge parts
  moved to the front of the board with the 14 mm bezel, and the tallest of
  them — the Alps buttons at 3.3 mm and the USB-C shell at 3.2 — stand in a
  bay that is about 5 mm deep, so there is roughly 1.7 mm between them and a
  plate lying against the case's inner face. That is enough, but it is not a
  lot, and it is a short rather than a scratch if the plate ever sags onto the
  USB-C shell. Either relieve the plate over that strip or make sure the case
  supports it there.
- **The plate must not reach the antenna.** The module sits at the bottom edge
  with its antenna overhanging the board outline, so it is in the bottom few
  millimetres of the case. Steel directly over it will detune it badly. **Stop
  the plate at the keyboard's bottom edge, case Y 9**, and leave the 9 mm chin
  printed — which is where the original's badge goes anyway. Even then, check
  BLE range on the first build with the plate on and off. This one is a
  measurement, not a calculation.

One thing the plate buys for free: **the display aperture gets a crisp etched
edge** instead of a printed one. That is the same aperture worked out in
`docs/display-mounting.md`, 56.00 mm wide and centred on the case, and it will
look considerably better in steel. It does not buy back the 24th character
column — that needs 58.06 mm and the active area only allows 57.04 — so the
display stays 23 × 6 either way.

## The window

**On its own, I would not.** The panel already has a hard-coat antiglare
surface, so a window adds protection you mostly have and takes away contrast
you cannot spare.

E-paper is reflective: light goes in through the front and comes back out the
same way. A window with an air gap behind it adds two more glass-to-air
interfaces, each reflecting about 4%, and that shows up as veiling glare on a
display whose contrast ratio is only about 10:1 to begin with. It is not a
rounding error on a reflective display the way it would be on a backlit one.

If a window goes on anyway, **optically bond it** — an optically clear
adhesive sheet, the way e-readers are assembled — or at minimum use an
anti-reflective coated one. Do not leave a plain air gap.

## The frontlight

This is a real technique, not a hopeful one: every Kindle Paperwhite and Kobo
has exactly this, an edge-lit guide **in front of** the e-paper rather than a
backlight behind it, which reflective displays cannot have.

Barnaby brought back a second opinion on 21 September 2026 from a separate
conversation with another assistant. It is good work and it moved three things
here. What follows is the merged version; where the two answers disagreed, the
reason for the winner is given.

### The guide: 1.0 mm cast acrylic

I had said 1.5–2 mm. **1.0 mm is better and the other answer's reasoning is
the better reasoning**: below 1 mm the sheet warps under the engraving pass,
above it the parallax grows, and 1.0 mm is the thickness that matches the
profile height of the side-view LEDs you can actually buy. All three of those
are true and the third is the one I had not thought about.

Parallax is the part worth putting numbers on, because it is the cost the user
sees. A 1.0 mm sheet bonded down with about 0.175 mm of optically clear
adhesive puts 1.175 mm of plastic over the ink. Tilt the calculator and the
image slides sideways by

| tilt from normal | 1.0 mm guide | 2.0 mm guide |
|---|---|---|
| 20° | 0.28 mm (0.7 logical px) | 0.51 mm (1.3) |
| 30° | 0.42 mm (1.0 logical px) | 0.78 mm (1.9) |
| 45° | 0.63 mm (1.6 logical px) | 1.17 mm (2.9) |

A logical pixel here is `EPD_SCALE_X` = 2 device pixels, 0.406 mm. So at 1.0 mm
a normal viewing tilt costs about one pixel of float; at 2.0 mm it is two, and
characters start to look like they are swimming above the glass. That settles
it.

**Cast acrylic, not polycarbonate** — and that is a real change, because the
window idea started out as polycarbonate. A CO₂ laser at 10.6 µm cuts cast
acrylic cleanly and chars polycarbonate: yellow edges, no polish, and a
discoloured engrave. Extruded acrylic is also wrong; it engraves grey and
muddy rather than frosted white. This costs something — acrylic is more
brittle and scratches more easily than polycarbonate — but the guide sits
recessed under the etched steel bezel, which takes the handling, and it is
bonded down so it cannot flex. It is also the right optical choice
independently: every commercial light guide plate is PMMA, because
polycarbonate's higher dispersion tints a long light path yellow.

Extraction is a **density-graded dot pattern engraved on the top face**,
sparse at the injection edge and dense at the far edge. The grading is the
whole craft of it; expect to cut several before one looks even. Glowforge
settings that the other answer gave and that match what the process wants:
vector dot grid, dots 0.1 mm at the near edge growing to 0.3 mm at the far
edge, engrave at high speed and low power (of the order of speed 1000, power
10–15, 450–675 LPI) so the beam frosts rather than craters, masking removed
for the engrave, and the injection edge flame-polished afterwards. Treat those
as a starting point to bracket, not as settings.

**The guide is the window.** It is a sheet of acrylic lying on the panel, so it
protects the glass and there is no reason to have a separate window as well.

### Where the LEDs go, and how far off they are

The guide lies on top of the panel, so its edge is well above the board while
a side-view LED soldered to the board emits close to it. Now that the guide is
1.0 mm the mismatch can be stated exactly:

| | height above the board's top copper |
|---|---|
| panel adhesive | 0 → 0.1 mm |
| panel glass | 0.1 → 1.1 mm |
| guide | 1.1 → 2.1 mm, optical centre **1.6 mm** |
| a 1208 LED soldered flat to the board | centre **0.5 mm** |

1.1 mm out, which is most of the light. The fix is one small part: **a 1.0 mm
FR4 sliver lying on the main board** carrying the four LEDs. Its top surface is
then at 1.0 mm, the LED centres at 1.5 mm, and the guide's centre is at 1.6 —
0.1 mm out, which is nothing. Two pads on the main board and two short wires
connect it. That keeps the height problem in mechanical parts, where it is
cheap to iterate, and out of the main board, where it is not.

The strip of free board between the panel and the keyboard, board Y 48.3 to
59.0, is 10.7 mm deep and full width. That is where the sliver and its pads go,
injecting into the guide's bottom edge and lighting upwards across the 30.7 mm
short axis of the active area. It was 16.7 mm until the bezel went to 14 mm on
21 September 2026; 10.7 is still ample for a 4 mm sliver and the driver beside
it.

Two pieces of luck along that edge:

- The active area starts 2.798 mm in from the glass edge on this axis, so
  there is a **2.8 mm mixing zone that is already dead glass**. The near-edge
  hot spots have somewhere to blend before the first visible pixel.
- The aperture is 56.00 mm on a 60.088 mm active area, so roughly 2 mm at each
  end is already hidden behind the bezel. Four LEDs on a 15 mm pitch across a
  60 mm edge leave the corners as the dim spots, and the corners are the part
  the bezel covers.

### The LED

**Dialight 599-2Q01-147F.** White, 1208 right angle, 3.0 × 2.0 × 1.0 mm,
200 mcd typical at 20 mA, 130° viewing angle.

This is the same package and the same land pattern as the status LED already
on the board — `hp42s:Dialight_599_BiColor_1208_RA` — so the footprint is
drawn, checked and in the library already. Nothing new to generate.

The other answer suggested a Kingbright APPA3010. That series is real and is
explicitly the narrow-angle side-firing family, but the search result it was
reading was a KPA-3010EC, which is red/orange, so the white part number in it
should not be trusted without checking. It does not matter now that the
Dialight part lands on a footprint we already own.

130° sounds too wide for edge injection and is not. Light entering acrylic from
air is refracted into a cone of ±42° by Snell's law however wide it arrives, and
everything inside that cone totally-internally-reflects. So the wide part is
free, and it mixes faster and shortens the hot-spot zone at the edge.

### The drive circuit: the boost wins, and not for the stated reason

The other answer said series LEDs with a constant-current boost. I had said
four LEDs in parallel, 100 Ω each, straight off `SYS`, with the MAX17048
compensating the droop in firmware. **The boost is right and my circuit does
not work** — but the argument it gave (that series guarantees matched current)
is not the argument that kills mine. Current matching is a second-order worry
next to how crudely the extraction grading controls brightness anyway.

What kills it is the forward voltage. I had assumed 3.0 V. The real part is
**3.4 V typical, 2.9 to 3.7 V** over the bin. `SYS` is the cell, 3.0 to 4.2 V.
So at a half-empty cell there is no headroom at all, and at a low cell the
frontlight is simply off. No resistor value fixes that and no amount of
firmware compensation invents voltage. The fuel-gauge trick was a good save for
a problem that turns out not to be the problem.

So: **four LEDs in series, about 13.6 V, off a boost**. Series also collapses
four ballast resistors into one current-set resistor and makes the current
independent of the cell all the way down, which removes the firmware
compensation entirely rather than patching it.

The part is a **TPS61165**, which keeps the BOM on the same vendor as the
BQ25185, TPS63900 and TPD4E05U06 already here. 3–18 V in, up to 38 V out, so
the string is comfortably inside it; 200 mV feedback reference at 2%, so the
current-set resistor is 0.2 V ÷ I; 1.2 MHz; SOT-23-6 or a 2 × 2 mm WSON; PWM
brightness straight onto `CTRL` from a GPIO; and open-LED protection, which
matters more than usual because the LEDs are on a separate sliver at the end of
two wires.

| | current set | string | from the cell at 3.7 V | from 1600 mAh |
|---|---|---|---|---|
| reading level | 5 mA, R = 40 Ω | 12.4 V | ≈ 20 mA | ≈ 80 h |
| full | 20 mA, R = 10 Ω | 13.8 V | ≈ 88 mA | ≈ 18 h |

So the 80 hours quoted earlier is the dim setting, which is the one anybody
actually reads by, and full brightness is a 20-hour proposition. Either way it
**defaults off and turning it on is a deliberate act**, the way an e-reader's
is, against a design that otherwise claims 15 months.

The cost of conceding the boost is a second switching node on a board that
works hard to keep the first one — the panel's own DC-DC and its 47 µH
inductor — away from the SPI. Two things contain it: the frontlight switcher
sits at the right-hand end of the Y 42.3–59.0 strip, as far from the FPC
connector and the panel's converter at X 7–20 as the board allows, and it only
runs when the user has asked for light, which is not while the panel is being
refreshed in the dark.

### As drawn

This is now in the schematic, in `elec/src/frontlight.ato`, and wired into the
top level on **`IO41`**. `IO26` and `IO42` stay free and `IO40` stays spoken
for as the sounder's antiphase pin.

Nine parts on the main board:

| | | |
|---|---|---|
| U | TPS61165DBVR | SOT-23-6 |
| L | 22 µH, NR3015T220M | 3.0 × 3.0 × 1.5 mm. TI's own optimum, not a guess — §9.1.2 recommends 10–22 µH and says 22 is the efficient end |
| D | 1N5819HW | the same Schottky as the panel's charge pump, so no new BOM line |
| C | 4.7 µF | input, 0603. TI ask 1 µF minimum |
| C | 1 µF 50 V | output, 0805 — **not 25 V**, see below |
| C | 220 nF | COMP |
| R | 10 Ω | current set: 0.2 V ÷ 20 mA, the LED's rated maximum |
| R | 10 kΩ | in series with CTRL |
| R | 1 MΩ | holds CTRL down |

plus two solder pads, `FL+` and `FL−`, and the four LEDs on the sliver.
Thirteen active parts rather than the seven the parallel scheme would have
taken.

**The output capacitor is the one thing here that could have gone bang.** In
normal running it sees 13.8 V, which a 25 V part covers comfortably — and that
is what this was until the datasheet arrived. What sets the rating is the
fault. If the LED string opens, the boost runs the output up until the open-LED
protection trips, and TI put that threshold at 37 V minimum, 38 typical and
**39 V maximum**. A 25 V part there fails, and it fails with 39 V behind it.
50 V in 0805, because a 50 V 0603 would lose most of its capacitance to DC bias
derating at 13.8 V. The same number is why the Schottky has to be a 40 V part:
TI's own recommendations for this position, the MBR0540 and ZHCS400, are both
40 V. That is only 1 V of margin on a fault that LEDs at the end of two
hand-soldered wires can genuinely produce, so a 60 V PMEG6010CEH in the same
SOD-123 outline is worth the BOM line if you want it.

**Both CTRL resistors are the datasheet's, not my taste.** The 10 kΩ in series
is there because CTRL is not only a PWM input — it is also the EasyScale
one-wire interface, and the part can pull CTRL down itself to acknowledge a
command. TI recommend a series resistor limiting CTRL current to 500 µA when
the driver is push-pull, which an ESP32 GPIO is, both for an accidentally
requested acknowledge and to protect the internal ACKN-MOSFET. 3.3 V over 10 kΩ
is 330 µA. The 1 MΩ pull-down sits on the IC side of it: CTRL low is shutdown,
and the driving GPIO is high impedance at reset and through boot, so without it
the frontlight's state during boot is whatever leakage decides. 4.7 MΩ would
cost a fifth as much standing current but leaves CTRL at nearly half a volt,
too near the threshold to trust. The two divide 3.3 V by 1.01, so CTRL still
sees 3.27 V high.

Two soldered wires to the sliver rather than a connector: a connector inside a
case that is never opened is a part that can work loose, and it would have to
be under 1 mm tall to fit beside the guide.

**The two lands on the main board are now 2.0 x 2.0 mm** (`TP1` and `TP2`,
`SliverLand` in `parts.ato`), changed on 24 September 2026 from the 1.5 mm round
test-point pads they had been. Nothing probes them: a wire carrying about 88 mA
is soldered to them once and stays. A square gives an iron somewhere to sit and
takes the wire laid flat.

**How the wires join the sliver is still open, and it is a height problem.** The
guide's edge runs from 1.1 to 2.1 mm above the board's top copper, and that is
the window the LEDs sit in — a 1.0 mm sliver with a 1208 part on top reaches
2.0 mm. So a wire soldered to a pad on the sliver's *top* face, at about 1.4 mm,
lands in the same window and fouls the guide. Three ways out, in the order I
would try them:

1. **Castellated half-holes at the two ends of the sliver.** The wire solders
   into a plated notch in the edge and adds nothing above the sliver's own
   1.0 mm. It is the clean answer and it costs a fab option and a footprint this
   repo would have to draw.
2. **Make the sliver longer than the guide is wide** — say 64 mm against 60 mm
   of LEDs — and put plain top-face pads on the 2 mm that stick out at each end.
   No new footprint, no fab option. Whether the overhang is there is a question
   for the guide's width, which the case model owns.
3. **Bottom-face pads reflowed straight onto `TP1` and `TP2`.** Lowest of all,
   and it throws away the strain relief the wires were chosen for, over a 60 mm
   span between two different boards.

This is the thing to settle before the sliver gets drawn, and (2) needs one
number from the case model: how wide the guide actually is.

**Settled 27 September 2026: option 2.** Barnaby's guide is an acrylic
rectangle about the size of the display window, so at most 60 mm across the
injection edge. A 64 mm sliver therefore overhangs it by 2 mm or more at each
end, and plain top-face pads go there. No castellations are needed.

Cut the guide a little bigger than the window rather than exactly to it. The
extra is about 3 mm on the LED edge, to the glass edge, plus a millimetre on
the other three sides. The LED edge then sits in the 2.8 mm of dead glass,
where the hot spots can mix before the first visible pixel. The faceplate
clamps the margin, and a cut edge never shows in the window. That gives
roughly 60 x 34 mm, still inside the 64 mm sliver.

**The sliver is drawn (28 September 2026):** `elec/layout/sliver/sliver.kicad_pcb`,
written by `tools/make_sliver.py`. It is its own board, not a second outline on
the main one: it is 1.0 mm with copper on one face and the main board is 1.6 mm
with four layers, and a fab builds each order to one thickness and stack-up. 64 x
4 mm; LEDs at 9.5, 24.5, 39.5 and 54.5 mm with their lenses flush with the top
edge (`LED EDGE` on the silk); `FL+` and `FL-` are 1.5 x 3.0 mm pads 0.25 mm in
from each end. Order it as 1.0 mm FR4, 1 or 2 layers (B.Cu is empty).

**What it costs when it is off.** `SYS` is the cell, so the driver is live
whenever there is a cell in the case: the TPS61165's shutdown current plus 4.2 µA
through the 1 MΩ comes to about **5 µA**. Against a board that otherwise sits at
21 µA asleep — there is no switched-off state since the slider went on
24 September 2026, see `docs/power-control.md` — that is a quarter on top. It is
a real cost and it is the reason the whole block is fitted per unit: a calculator
built without a light guide has none of these parts on it and none of the 5 µA.

Both numbers are far below what the cell loses to self-discharge, which is the
thing that actually empties a calculator left in a drawer.

### Bonding

Optically clear adhesive, 125–175 µm, the way e-readers are assembled. Pre-cut
phone-repair sheets are the cheap source; 3M 8211/8212/8215 or Lohmann
DuploCOLL are the named products. Laser-cutting OCA is possible but it is a
sticky, fumey job — cutting it oversize with a blade against a template and
trimming after lamination is less trouble. Roll it on from one edge to chase
the bubbles out, and do it in the least dusty room in the house, because every
speck under it is permanent.

## What I would build

1. **The plate, now.** It is the lowest-risk, highest-return item on this list,
   and the aperture is already specified. The only board change it asks for is
   a ground bond pad.
2. **No separate window** — if the frontlight happens the guide is the window,
   and if it does not, the panel's own hard coat is enough.
3. **The frontlight as an option — now drawn.** Thirteen parts and one GPIO is
   cheap enough that leaving room for it costs nothing, and the light guide is
   the part that might not come out well, which is a question of laser time
   rather than of board respins. The circuit is in `elec/src/frontlight.ato`;
   a unit built without a guide simply does not have any of it fitted.

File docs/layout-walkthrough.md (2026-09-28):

# Laying out this board in KiCad, step by step

This is the click-by-click version, written for someone who has not done a PCB
layout before. It assumes nothing except that KiCad 10 is installed and this
repo is on your machine.

`docs/pcb-process.md` is the map of the whole job, from netlist to boards in
your hand. **This file is steps 2 to 7 of that map, in detail.** When you are
done here you will have a finished board file, and you go back there for the
fabrication outputs, the ordering and the bring-up.

Everything below was checked against KiCad 10's own source, so the menu paths
and the keyboard shortcuts are the real ones, not remembered ones.

---

## What you are actually about to do

The netlist already says what connects to what. It says nothing about *where*.
Layout is the job of deciding where each of the 119 parts sits on a 76 × 144 mm
rectangle, and then drawing the copper that makes the 83 connections real.

There are five distinct activities and they are not equally hard:

| | What | How long |
|---|---|---|
| A | Set the project up | 30 minutes, once |
| B | Import and place the parts | an evening, and you will redo it |
| C | Route the copper | two or three evenings |
| D | Pour the ground planes | an hour |
| E | Check it | an hour, and worth two |

B is the one that matters. A good placement makes the routing almost draw
itself; a bad one makes it impossible, and you find out four hours in. This is
why step 6 places everything by script and step 7 is where you argue
with it.

### Two rules before you start

**Commit after every numbered step.** The board file is text and git will diff
it. When something goes wrong at step 9 you want to be able to go back to the
end of step 8, not to the beginning.

```bash
cd "/Users/barnaby osborne/Documents/Personal/02 Projects/Calculator/Hp42s_calc1"
git add -A && git commit -m "layout: step N done" && git push origin main
```

**Push every time, not just commit.** I cannot see your machine — the pushed
repo is the only version of the board I can look at. "I have done step 8, can
you check" only works if step 8 is on GitHub.

**Quote the path in every shell command.** The checkout lives at

```
/Users/barnaby osborne/Documents/Personal/02 Projects/Calculator/Hp42s_calc1
```

which has spaces in it in three places. Unquoted, bash reads
`cd /Users/barnaby osborne/...` as *cd to `/Users/barnaby`, with `osborne/...`
as a second argument*, and you get "No such file or directory" pointing at a
path that plainly exists. The shell commands below are already written with the
quotes in. Python is not affected — `open('...')` takes the whole string — so
the scripting console in step 6 needs no special treatment.

**Do not fight the software.** If a step does not behave the way this file says
it will, stop and say so rather than working around it. Everything here is
checked, but it is checked against source code, not against your screen.

---

## Step 1 — Learn six keys and one panel

Five minutes here saves an evening later. KiCad is modal and hover-driven in a
way that is unusual, and fighting it is most of a beginner's pain.

### The thing that trips everyone up

**KiCad acts on whatever the mouse is hovering over, not on what you clicked.**
Hover a footprint and press `M` and it starts moving — no click needed. If you
click first and then move the mouse away, the key still applies to the thing
under the cursor. Keep the pointer on the thing you mean.

### The six keys

| Key | Does |
|---|---|
| `M` | Move the thing under the cursor. Click to drop it. |
| `R` | Rotate 90° anticlockwise. `Shift+R` goes the other way. |
| `F` | Flip to the other side of the board. |
| `E` | Open its properties dialog. |
| `Esc` | Cancel whatever you are in the middle of. |
| `Ctrl+Z` | Undo. Works on everything, including a whole script run. |

`Delete` or `Backspace` deletes. `Ctrl+0` zooms to fit the board, which is how
you find things you have lost.

### The panel on the right

It is called the **Appearance** panel. If it is not showing, **View → Panels →
Appearance**. It has tabs across the top; the one you live in is **Layers**.

Two different things happen in that tab and it is worth knowing they are
different:

- **Clicking a layer's name makes it the active layer**, and the active layer
  is where new tracks go. This is the single most common source of "why is my
  track on the wrong side of the board".
- **The checkbox beside it hides or shows that layer.** Hiding is not deleting.
  Turning off `B.Cu` while you work on the front is normal practice and changes
  nothing about the board.

### Two more worth knowing now

- `Ctrl+U` switches between mm and inches. **Work in mm.** Everything in this
  repo is mm. If a dialog shows inches, press it.
- `Ctrl+Shift+M` is the measuring tape. Use it constantly.

---

## Step 2 — Make the project

KiCad needs a project file to hang a board off. It does not exist in this repo
yet.

Neither does the folder it goes in, in a fresh clone: git cannot store an empty
directory, so `elec/layout/` only appears once something is in it. Make it
first:

```bash
cd "/Users/barnaby osborne/Documents/Personal/02 Projects/Calculator/Hp42s_calc1"
mkdir -p elec/layout
```

1. Open **KiCad** (the project manager, the one with the workflow icons).
2. **File → New Project…**
3. Navigate into this repo, to `elec/layout/`.
4. Name it `default`. Leave "Create a new folder for the project" **ticked**.
5. Save.

You now have `elec/layout/default/default.kicad_pro` and a `.kicad_pcb` beside
it. That exact path matters — the footprint library path in step 3 is written
relative to it.

6. In the project manager, double-click **`default.kicad_pcb`** to open the PCB
   editor. This is the window you will live in.

You will never open the schematic editor. atopile is the schematic; the `.ato`
files in `elec/src/` are the drawing, and `build/default.net` is what comes out
of them.

**Done looks like:** an empty PCB editor with a blank sheet, and the title bar
saying `default.kicad_pcb`.

```bash
git add -A && git commit -m "layout: empty KiCad project" && git push origin main
```

---

## Step 3 — Point KiCad at this repo's own footprints

Seven of the 28 footprints on this board do not exist in KiCad's libraries —
the two dome sites, the two TI leadless packages, the side-looking IR emitter,
the status LED and the side-push recovery button. They live in
`elec/footprints/hp42s.pretty/`, generated by `tools/gen_dome_footprints.py`
and `tools/gen_ic_footprints.py` from the vendors' own drawings.

Without this step the netlist import fails on 44 of the 119 parts.

1. In the **PCB editor**, **Preferences → Manage Footprint Libraries…**
2. Choose the **Project Specific Libraries** tab, not Global. The path below
   only makes sense inside this project.
3. Add a row. There are two buttons under the table and either will do: the one
   whose tooltip reads **"Add empty row to table"** gives you a blank line to
   type into, and **"Add Existing"** opens a file picker you can point at
   `elec/footprints/hp42s.pretty` and let KiCad fill in for you.

   Whichever you use, the row has to end up reading:

   | Column | Value |
   |---|---|
   | Nickname | `hp42s` |
   | Library Path | `${KIPRJMOD}/../../footprints/hp42s.pretty` |
   | Library Format | `KiCad` |

   `${KIPRJMOD}` is KiCad's variable for "the folder this project is in", so
   the path means *up two levels from `elec/layout/default/`, then into
   `elec/footprints/`*. If you used the file picker and it filled in an
   absolute path like `/Users/barnaby/…`, click the cell and retype it as
   above. The absolute one works on your machine today and nowhere else.

4. **OK**.

**Check it before moving on: View → Footprint Library Browser.** A window opens
with every library listed down the left. Click `hp42s` and you should see
**nine** entries:

```
Alps_SKRTLAE010_SidePush
Dialight_599_BiColor_1208_RA
Dialight_599_White_1208_RA
Dome_4Leg_10mm
Dome_4Leg_8.5mm
SameSky_UJ20-C-H-G-SMT-1A-P16_USB-C
TI_DQA0010A_USON-10_2.5x1mm_P0.5mm
TI_DSK0010A_WSON-10-1EP_2.5x2.5mm_P0.5mm_EP2x1.2mm
Vishay_VSMB2943SLX01_SideView
```

Nine, but only seven get used. `Dialight_599_White` belongs to the frontlight
LEDs, which sit on a separate sliver of FR4 and are not on this board.
`SameSky_UJ20` is the USB-C receptacle this board used to have before it moved
to the GCT part on 22 September 2026; it is kept only so old board files still
open.

If `hp42s` is not in the list at all, or is there but empty, the path is wrong.
Check that `elec/footprints/hp42s.pretty/` really is two levels up from your
project folder — from `elec/layout/default/`, `../../footprints/` should land
you in `elec/footprints/`.

---

## Step 4 — Board Setup, before there is anything on the board

Do this now rather than later. Changing the layer count after you have routed
is possible but unpleasant, and the net classes decide how wide your tracks
come out, so setting them first means you never have to go back and widen
anything.

**File → Board Setup…** opens a dialog with a tree down the left side.

### 4a. Layers

Go to **Board Stackup → Physical Stackup**. At the top, set **Copper Layers:
4**. (Some builds put that selector on the **Board Editor Layers** page just
above it instead; either is the same setting.)

Leave the **board thickness at 1.6 mm**, which is KiCad's default.

It was 1.0 mm until 23 September 2026, on the reasoning that a 15 mm case with
a cell on the back of it could use the 0.6 mm. Barnaby asked whether that would
flex under 37 dome switches. It would: a 1.0 mm board supported only at its
edges moves about 0.28 mm under a firm press, against 0.5 mm of dome travel,
which would make every key feel dead. 1.6 mm is 4.1× stiffer, the stack-up had
2.6 mm of slack to pay for it, and the panel's fold geometry had assumed
1.6 mm all along. The working is in `docs/board-thickness.md`.

The case stays at 15 mm.

You will now have four copper layers: `F.Cu`, `In1.Cu`, `In2.Cu`, `B.Cu`.

What each is for on this board:

| Layer | Use |
|---|---|
| `F.Cu` | dome pads, the panel's connector, short signal runs |
| `In1.Cu` | **solid ground.** Do not cut it up. |
| `In2.Cu` | 3.3 V pour over the whole layer, with the keypad column and row nets routed through it |
| `B.Cu` | everything else, and a second ground pour |

The keypad matrix has to live on an inner layer because nothing can route
between the numeric dome sites on the front: they clear each other by 1.6 mm
and their courtyards by 0.6 mm. Each dome ring gets a via placed outside its
courtyard and drops to `In2.Cu`.

### 4b. Constraints

Go to **Design Rules → Constraints**.

Everything on this page is a **floor**, not a value. Nothing here decides how
wide your tracks come out — that is the net classes in 4c. These exist only to
make DRC shout when you draw something the fab cannot make, so the right
numbers are your fab's capabilities, not your preferences.

Four to set, in the **Copper** and **Holes** groups on the left:

| Setting | Value | Why |
|---|---|---|
| Minimum clearance | `0.2 mm` | every cheap fab beats this comfortably |
| Minimum track width | `0.15 mm` | you will not go this thin; it is the floor |
| Minimum via diameter | `0.5 mm` | see below — this one has to agree with the next two |
| Minimum drill size | `0.3 mm` | the smallest hole a cheap fab will drill without a surcharge |

And **leave "Minimum annular width" at KiCad's `0.1 mm`.**

**Those three numbers have to agree with each other**, which is the part that
is easy to get wrong. The annular ring is the copper left around a hole, so

```
annular width = (via diameter − drill) / 2
```

At a 0.5 mm via on a 0.3 mm drill that is exactly 0.1 mm, which is what the
annular rule asks for and what a cheap fab quotes. A 0.45 mm via on the same
drill gives only 0.075 mm, so a via drawn at the minimum diameter would fail
the annular rule — an internally inconsistent set of limits, which is worth
avoiding even though nothing on this board is drawn anywhere near these floors.
(The net classes in 4c use 0.6/0.3 and 0.8/0.4, so 0.15 and 0.2 mm of ring.)

**Leave every other field on the page alone.** KiCad's defaults are right for
this board and several of them matter:

- **Copper to edge clearance `0.25 mm`** (Barnaby, 27 September 2026; it was
  0.5). The two LEDs and two buttons on the top edge have to reach the outline
  to show through the case, and their pads sit about 0.3 mm from it, so 0.5 gave
  eight deliberate DRC errors. 0.25 is still inside what any fab routes to. The
  pours stay 0.5 mm back regardless, because the zones' own clearance is 0.5.
  The scripts in `tools/` also keep new copper 0.5 mm from the edge.
- **uVias** are microvias and there are none on this board.
- **Silk minimum text height `0.8 mm`** is about the smallest a fab will print
  legibly, and you have 38 dome sites to label.

These are all deliberately loose. A board this dense does not need fine-pitch
rules anywhere except under the module, and paying for tighter tolerances would
be paying for nothing.

### 4c. Net classes

*These* are the numbers that decide what gets drawn, as opposed to 4b's floors.
Each class says how wide a track on its nets comes out and how big its vias
are, and you can change a class later and have every net on it follow.

Go to **Design Rules → Net Classes**. The columns are `Name`, `Clearance`,
`Track Width`, `Via Size`, `Via Hole`, then `uVia Size`, `uVia Hole`,
`DP Width`, `DP Gap`, `Tuning Profile` and a `PCB Color` swatch. Only the first
five and the colour matter here; the microvia and differential-pair columns are
for things this board does not have.

There is a `Default` class already. Set it to `0.2` clearance, `0.2` track,
`0.6` via size, `0.3` via hole. Then add two more with the **+** button under
the table:

| Class | Clearance | Track Width | Via Size | Via Hole | For |
|---|---|---|---|---|---|
| `Default` | `0.2` | `0.2` | `0.6` | `0.3` | everything not named below |
| `power` | *blank* | `0.5` | `0.8` | `0.4` | the rails |
| `keypad` | *blank* | `0.2` | `0.6` | `0.3` | the 13 matrix nets |

**Leave a cell blank when you want Default's value.** These fields are optional
in KiCad 10, and the effective rules for a net are built by starting from
`Default` and letting the assigned class overwrite only the fields it actually
has set. So a blank `Clearance` on `power` is not "no clearance", it is
"whatever `Default` says" — and it stays right if you ever change `Default`.
Typing `0.2` into all three works too; it is just three places to remember
instead of one.

**`keypad` is deliberately identical to `Default`, and that is not a mistake.**
The matrix carries no current worth the name — a dome contact against a
pull-up, microamps — so there is nothing to make its tracks wider for, and
nothing about it that wants a different via.

It exists for a different reason, and you will be glad of it when you route.
In the
**Appearance** panel there is a **Nets** tab with a **Netclasses** section, and
right-clicking a class there gives you **Set Netclass Color** and **Hide All
Other Netclasses**. The keypad matrix is 13 nets across 38 dome sites, which is
most of the ratsnest on this board; being able to colour it, or switch it off
entirely while you place the power parts, is the difference between a readable
ratsnest and a grey fog. A class is the only handle KiCad gives you for that.

So set a colour on it while you are here — anything that stands out — and one
on `power` too.

### The half that actually does something

**The classes above apply to nothing until you assign nets to them.** That is
the **Netclass Assignments** table in the lower half of the same page, and it
starts empty. Add rows with its own **+** button — the one under *that* table,
not the one under the class list. Patterns use `*` as a wildcard:

| Pattern | Net class |
|---|---|
| `sys` | `power` |
| `bat` | `power` |
| `cell` | `power` |
| `v3v3` | `power` |
| `vbus` | `power` |
| `lx1` | `power` |
| `lx2` | `power` |
| `row*` | `keypad` |
| `col*` | `keypad` |

`gnd` stays on `Default` because it is going to be a poured plane, not tracks,
and the class width would only apply to the stubs.

Nine rows. If that table is empty when you close the dialog, `power` and
`keypad` exist and do nothing, every net is `Default`, and the rails come out
at 0.2 mm.

**The "Nets matching" panel on the right will be empty, and that is correct
right now.** It lists the nets on the board that a pattern catches, and the
board has no nets yet — they arrive with the netlist in step 5. Come back to
this page once they do; it turns into the cheapest check in this whole file.
Click each pattern in turn and you should see:

| Pattern | Nets | |
|---|---|---|
| `sys`, `bat`, `cell`, `v3v3`, `vbus`, `lx1`, `lx2` | 1 each | 7 |
| `row*` | `row0`–`row6` | 7 |
| `col*` | `col0`–`col5` | 6 |

**20 nets assigned, 63 left on `Default`.** A pattern showing 0 after the
import is a typo in the pattern, and a typo here is silent: the net simply
stays on `Default` and you find out when a 3 A rail turns out to be 0.2 mm
wide.

### 4d. Pre-defined sizes

Go to **Design Rules → Pre-defined Sizes** and add a couple of track widths you
will want to reach for by hand: `0.25 mm` and `0.8 mm`. During routing these
appear in a dropdown on the toolbar, so you can fatten a specific run without
editing its net class.

**OK** to close Board Setup.

```bash
git add -A && git commit -m "layout: 4-layer 1.6 mm stackup, net classes" && git push origin main
```

---

## Step 5 — Import the netlist

This is where the 119 parts arrive.

**First you have to build the netlist, because it is not in the repo.**
`build/` is in `.gitignore` — generated output does not belong in git — so
after a clone or a pull there is no `build/default.net` on your machine at all.
Run this before you go looking for it:

```bash
conda activate ato
cd "/Users/barnaby osborne/Documents/Personal/02 Projects/Calculator/Hp42s_calc1"
ato --non-interactive build
```

**The `conda activate ato` is not optional.** atopile lives in a conda
environment called `ato`, not in `base`, so a fresh terminal gives you
`-bash: ato: command not found`. `conda env list` shows the environments if the
name ever changes.

Note also that `--non-interactive` goes **before** `build`, not after. It is a
flag on the `ato` command itself, and putting it after gives you
`No such option: '--non-interactive'`.

It takes two to four minutes and ends with `Build complete!`. You now have
`build/default.net` and `build/default.csv`, the BOM.

Re-run it any time `elec/src/` changes, and re-import into KiCad afterwards.
That import is not a one-time operation and it does not disturb placement or
routing you have already done.

Now, in the PCB editor:

1. **File → Import → Netlist…**
2. **Netlist file:** browse to `build/default.net` at the repo root. Note that
   it is at the *repo* root, not under `elec/`.
3. **Link Method: "Link footprints using component tstamps (unique ids)".**

   **This one matters, and it is the opposite of what you might guess.** The
   other option links by reference designator. Do not use it.

   Here is why. atopile hands out designators in the order it meets components
   in the source. Add a resistor in the middle of `hp42s.ato` and everything
   after it shifts up one — I tested this on 22 September 2026 by inserting one
   resistor near the top of the file, and eleven resistors downstream of it got
   renumbered, `R14` through `R24` becoming `R15` through `R25`. The unique ids
   did not move at all. So designator linking would silently reassign eleven
   of your carefully placed parts to each other's positions, and tstamp linking
   just renames them in place.

4. **Options.** Leave **"Delete footprints with no components in netlist"** and
   **"Replace footprints with those specified in netlist"** ticked, and
   **"Group footprints based on symbol group"** and **"Delete tracks shorting
   multiple nets"** unticked. All four are already that way.

   **Untick "Delete/replace footprints even if locked".** KiCad ships it
   *ticked*, so this is an active change rather than something to leave alone.
   It costs nothing today, because nothing is locked yet, but the setting
   sticks: you lock the placed keypad at the end of step 6, and a re-import
   after that would walk straight through the lock and put all 38 dome sites
   back in the heap.

   Changing any option re-runs the preview on its own, so the list refreshes as
   you click.

5. **Press "Update PCB".** Not "Load and Test Netlist".

   Both read the netlist and fill the panel with the same list, but only
   `Update PCB` applies it; the other is a dry run, and it is the highlighted
   default button, so it is the easy one to press and feel finished. **The
   panel's own heading tells you which you are looking at**: it says *Changes
   to Be Applied* after a test, and *Changes Applied to PCB* after the real
   thing.

Read the message pane. **Expect `Total warnings: 9, errors: 0`.** Errors are
what matter, and there should be none. Every footprint resolves: 21 of the 28
from KiCad's own libraries, 7 from `hp42s`.

All nine warnings read `No net found for component <ref> pad <n>`, and all nine
are pins deliberately left unconnected:

| Part | Pads | Why |
|---|---|---|
| `U1` TPD4E05U06 | 6, 7, 9, 10 | TI marks them NC in table 4-2 of SLVSBO7O. Nothing inside the package touches them. |
| `U5` ESP32-S3-MINI-1 | 7, 26, 38, 41, 44 | `IO3`, `IO26`, `IO42`, `IO45`, `IO46` — spare GPIOs this design does not use. All 24 of the module's ground pins are connected. |

A warning naming any *other* reference or pad is not on this list and is worth
stopping for. If you imported before 23 September 2026 you will see 11 rather
than 9: the extra two are `J2 pad MP`, the display connector's metal hold-downs,
which are now tied to ground in `elec/src/display.ato`. Rebuild and re-import
and they go away.

If you see `Cannot add <ref> (footprint "hp42s:..." not found)`, step 3 did not
take — go back and fix the library path before doing anything else.

6. Close the dialog. All 119 footprints land in a heap near the origin,
   overlapping, with a dense cloud of thin lines between them. That cloud is
   the **ratsnest**: one line per connection that is not yet copper. It is
   supposed to look terrible.

**Done looks like:** 119 footprints on the sheet and no errors in the import
log. You can confirm the count with **Inspect → Show Board Statistics**.

```bash
git add -A && git commit -m "layout: import 119 footprints" && git push origin main
```

---

## Step 6 — Run the placement script

37 keys on a measured, non-uniform grid, plus a board outline with a notch in
it, plus seven parts whose positions were worked out to a hundredth of a
millimetre against case drawings. None of that should be done by dragging.

`tools/place_keypad.py` does it. It is a KiCad Python script and it runs
*inside* KiCad.

1. **Tools → Scripting Console.** A Python prompt opens in a panel.

   If that entry is not in the Tools menu, this KiCad was built without Python
   scripting — unusual for an official build, but it happens with some Linux
   distribution packages. Tell me and I will convert the script to something
   that edits the `.kicad_pcb` file directly instead.
2. Paste this, with the path adjusted to wherever the repo actually is:

```python
exec(open('/Users/barnaby osborne/Documents/Personal/02 Projects/Calculator/Hp42s_calc1/tools/place_keypad.py').read())
```

That is the real path on this machine, spaces and all; Python's quotes handle
them, so it needs no escaping. Use the **full absolute path** — the console's
working directory is not necessarily the project folder, and a relative path
here is the most common reason this step appears to do nothing.

3. Press Enter. It prints what it did:

```
top edge:
  D4    IR emitter    -> back, (25.33, 0.9)
  J1    USB-C         -> back, (38.0, 2.475)
  D5    status LED    -> back, (50.57, 1.05)
  SW39  reset         -> back, (71.31, 1.8)
  SW40  boot          -> back, (60.65, 1.8)
panel:
  J2    panel FPC     -> back, (9.0, 30.15), 90 deg -- check the mouth faces the left edge
  drew glass 71.82 x 36.30 on Cmts.User
  ...
drew a 76.0 x 144.0 mm outline on Edge.Cuts, with a 0.55 x 16.0 mm notch ...
placed 38 dome sites
```

If it throws a Python traceback, paste the whole thing back to me.

**Run it once and once only.** It is not idempotent: a second run draws a
second set of reference rectangles on `Cmts.User` on top of the first.
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

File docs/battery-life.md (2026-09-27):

# Battery life

`tools/battery_life.py` works out how long a charge lasts from the parts'
figures and a usage pattern. It needs nothing but Python 3.

    python3 tools/battery_life.py                        # the standard profiles
    python3 tools/battery_life.py --hours 1 --keys 600   # your own day
    python3 tools/battery_life.py --hours 1 --keys 600 --ble-min 30 --light-min 10 --frontlight
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

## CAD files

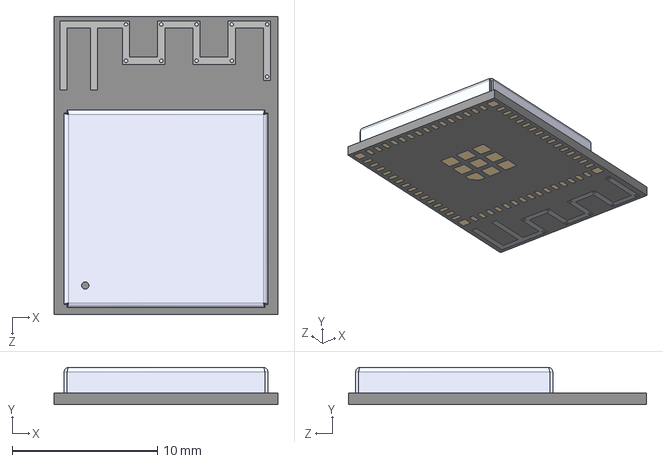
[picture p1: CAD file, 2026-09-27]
elec/footprints/vendor-3d/Espressif-ESP32-S3-MINI-1-N8.step
15.4 x 2.55 x 20.5 mm

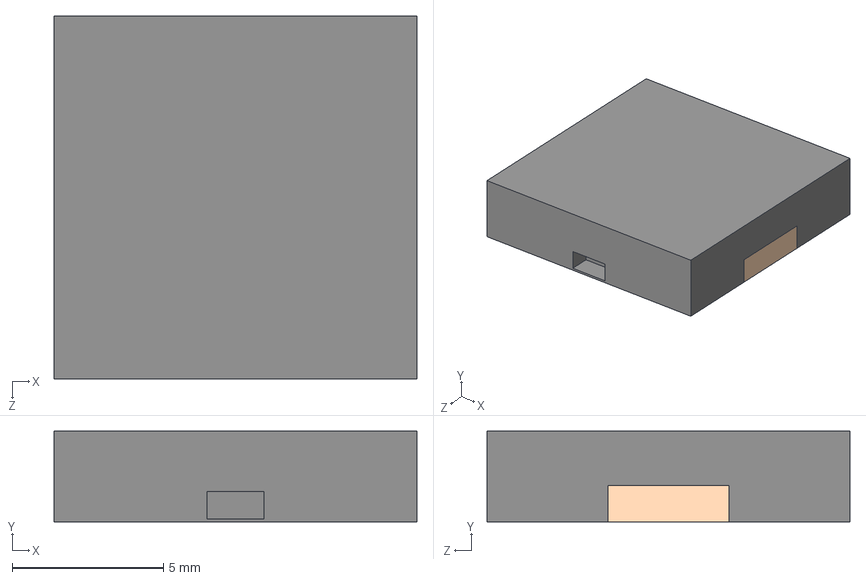
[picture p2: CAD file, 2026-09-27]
elec/footprints/vendor-3d/Murata-PKLCS1212E4001-R1.step
12.0 x 3.00 x 12.0 mm

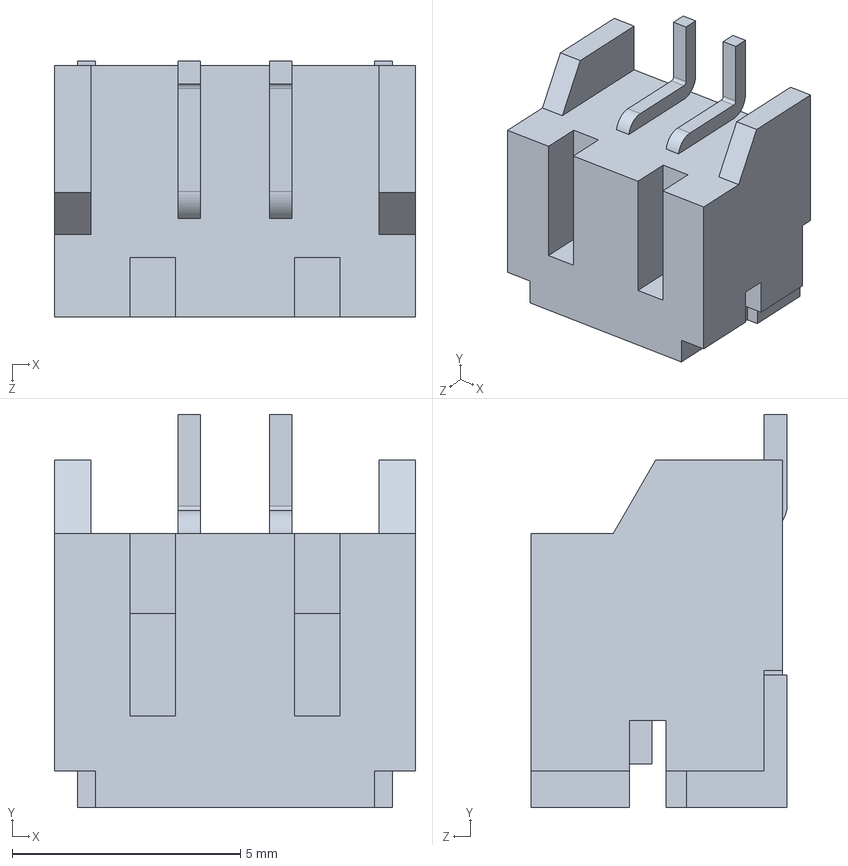
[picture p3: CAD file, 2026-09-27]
elec/footprints/vendor-3d/JST-S2B-PH-SM4-TB.step
7.90 x 8.60 x 5.60 mm

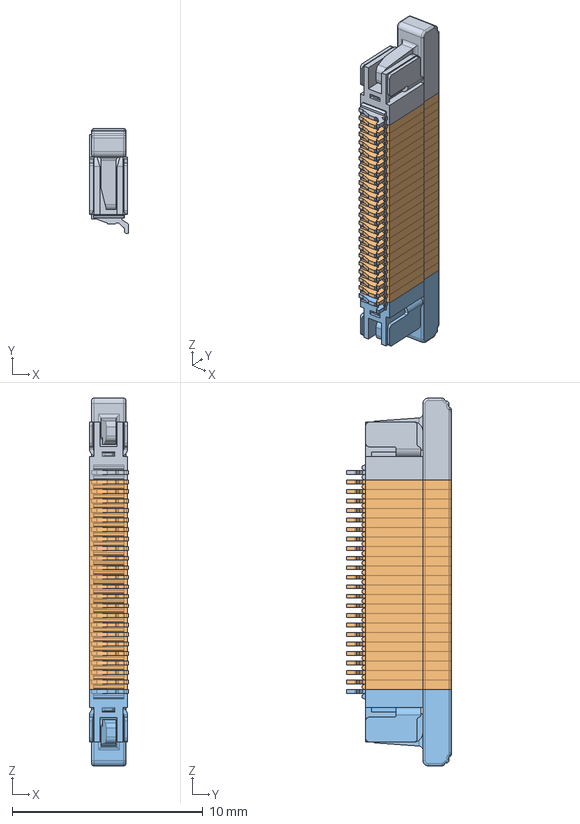
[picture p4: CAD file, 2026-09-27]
elec/footprints/vendor-3d/Amphenol-F32Q-1A7H1-11024.step
2.05 x 5.50 x 19.3 mm
F32Q_L
F32Q_M x 22
F32Q_R

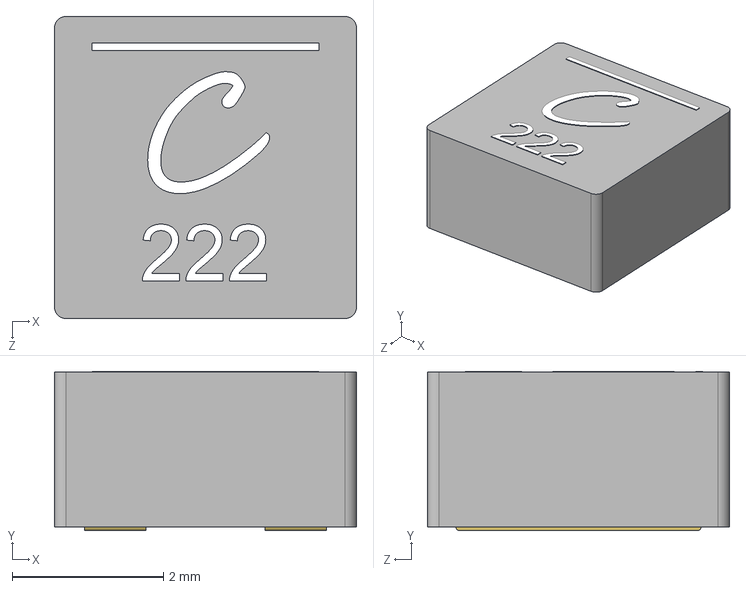
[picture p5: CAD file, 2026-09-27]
elec/footprints/vendor-3d/Coilcraft-XFL4020-222MEC.step
4.00 x 2.11 x 4.00 mm

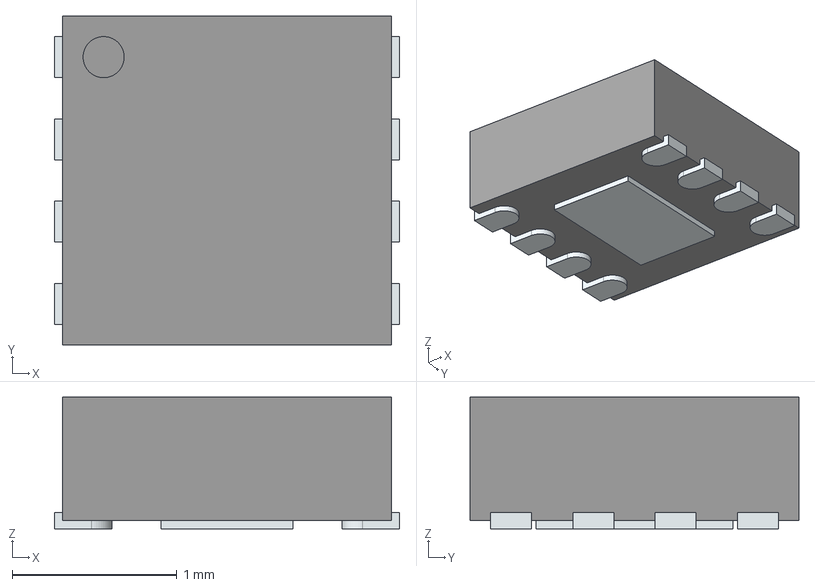
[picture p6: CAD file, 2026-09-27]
elec/footprints/vendor-3d/ADI-MAX17048GT10.step
2.10 x 2.00 x 0.8 mm
ThermalPin
PinsArrayLR

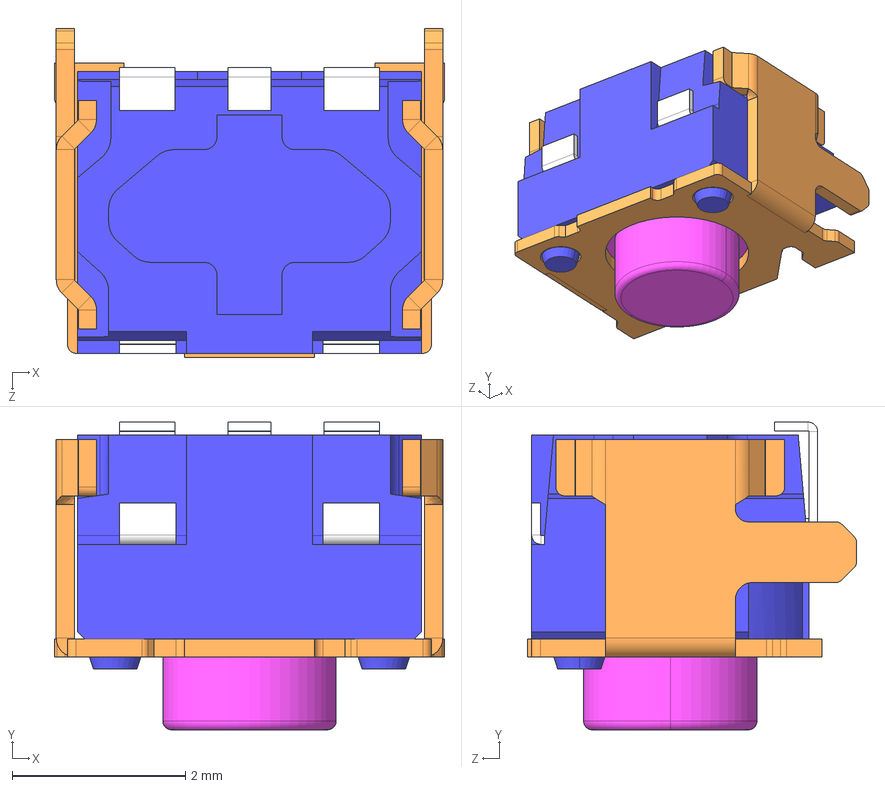
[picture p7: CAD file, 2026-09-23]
elec/footprints/vendor-3d/Alps-SKRTLA.step
4.50 x 3.55 x 3.80 mm

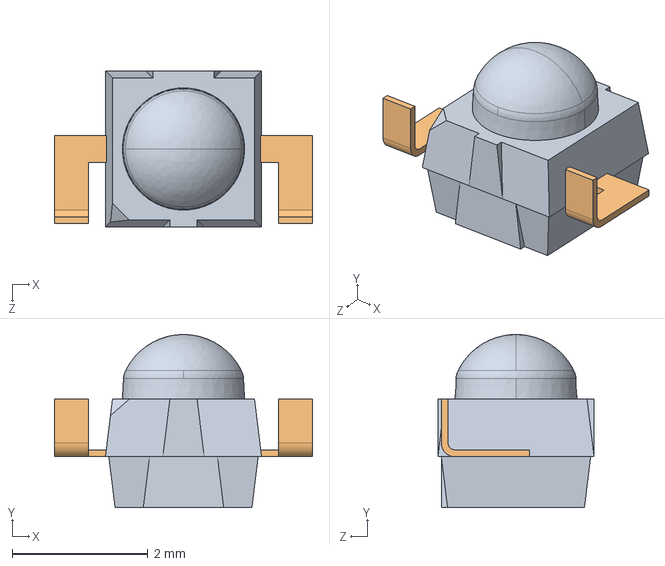
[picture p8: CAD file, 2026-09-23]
elec/footprints/vendor-3d/Vishay-VSMB2943SLX01.step
3.80 x 2.55 x 2.30 mm

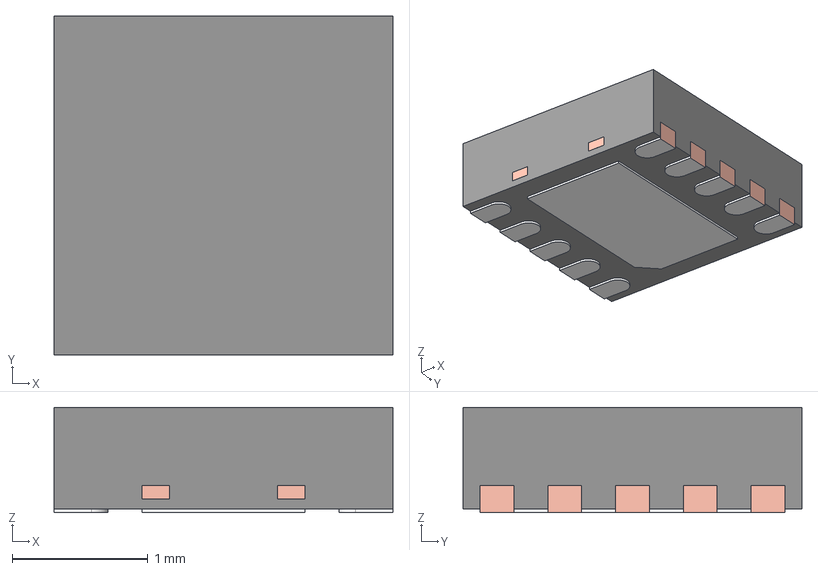
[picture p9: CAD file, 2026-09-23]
elec/footprints/vendor-3d/TI-DSK0010A.step
2.50 x 2.50 x 0.775 mm
BODY-SON
FRAME-DSK0010A
PIN1-ID

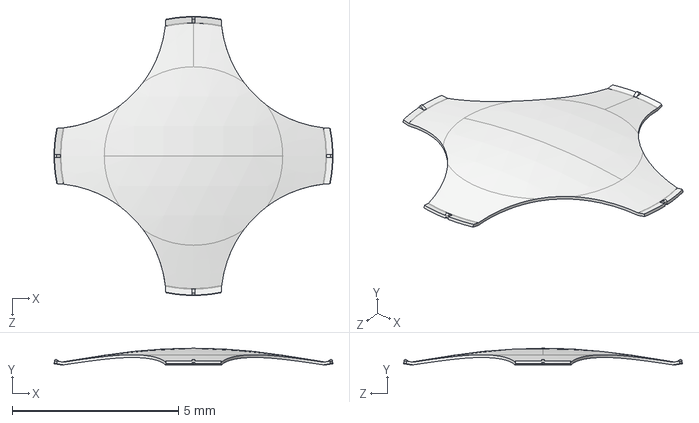
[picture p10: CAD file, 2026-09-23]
elec/footprints/vendor-3d/keystone-PN5134TR.step
8.40 x 0.5 x 8.40 mm

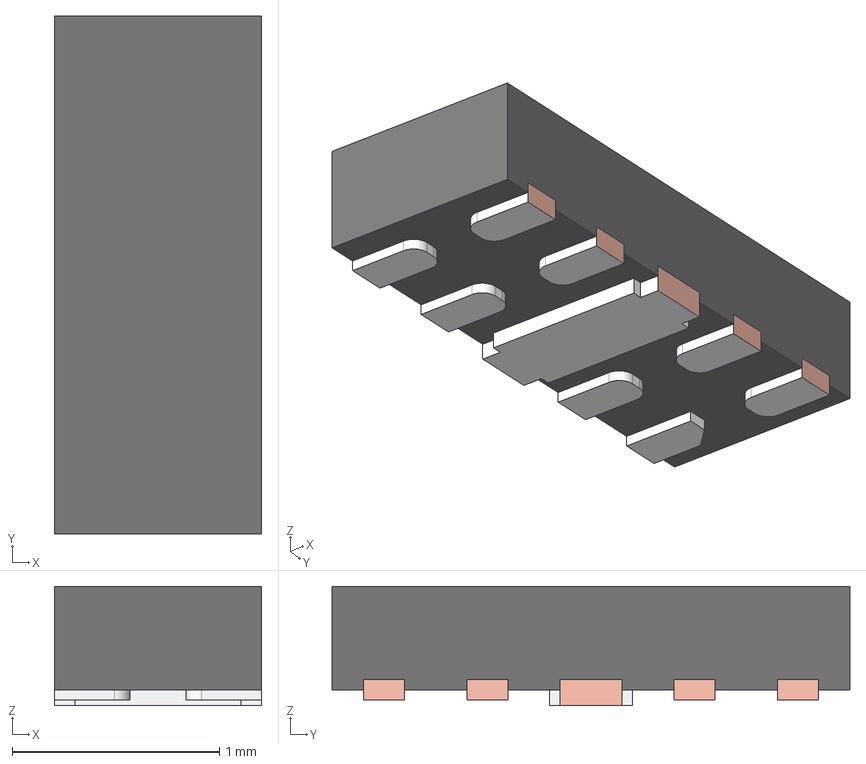
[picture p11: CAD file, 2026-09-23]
elec/footprints/vendor-3d/TI-DQA0010B.step
1.00 x 2.50 x 0.577 mm
DQA0010B_BODY
DQA0010B_FRAME
DQA0010B_PIN1-ID

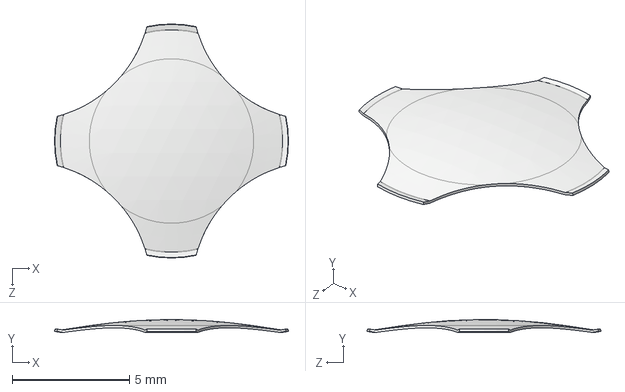
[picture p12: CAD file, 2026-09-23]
elec/footprints/vendor-3d/keystone-PN5154TR.step
10.0 x 0.544 x 10.0 mm

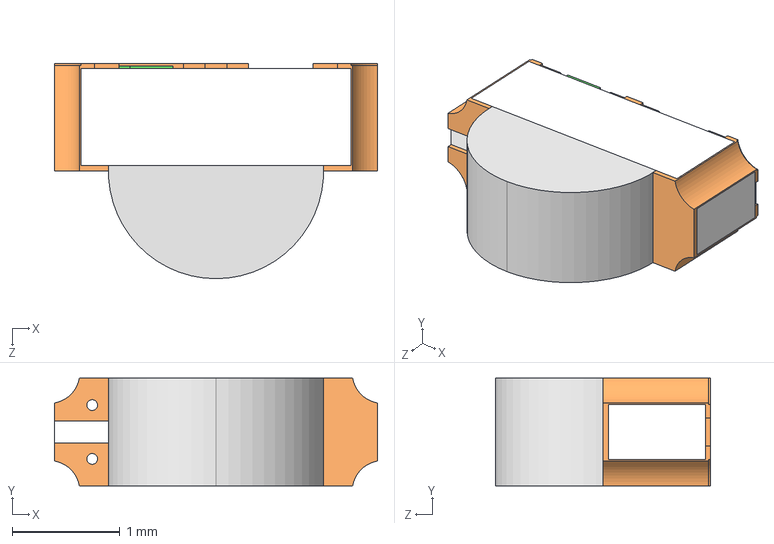
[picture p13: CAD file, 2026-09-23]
elec/footprints/vendor-3d/Dialight-599-0Q70-247F.step
3.00 x 1.00 x 2.00 mm

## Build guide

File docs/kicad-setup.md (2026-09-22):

# Getting the board into KiCad

**Start at `docs/layout-walkthrough.md` instead.** That file is the step-by-step
procedure — make the project, add the library, set the stackup, import the
netlist, run the placement script, place, route, check — and it supersedes the
three steps this file used to carry. `docs/pcb-process.md` is the map around it,
from netlist to boards in your hand.

What is left here is the part that is not a procedure: why the pin numbers on
this board are the way they are, and what reading the datasheets properly
turned up.

## Pin numbers: all of them are real now

KiCad matches a netlist pin to a footprint pad **by name**. Declaring a pin as
`IO33` against a footprint whose pads are called `1` to `65` matches nothing,
and the net imports silently unconnected -- no error, just missing ratsnest.
Every part on this board was once in that state. None is now.

The numbering came from the parts' own datasheets, except the ESP32's, which
came from KiCad's own `ESP32-S3-MINI-1` symbol. That symbol settles the
footprint question too: it points at `RF_Module:ESP32-S2-MINI-1` itself,
because the MINI-1 package is shared across the family.

Reading those datasheets properly turned up five things that were wrong rather
than merely unmapped, and any one of them would have cost a board:

- The **TPS63900 has no feedback divider**. Output voltage is set by resistors
  on CFG1/CFG2/CFG3, none of which may be left open. It is also a 2.5 x 2.5 mm
  WSON-10, not the VQFN-12 this repo claimed.
- The **BQ25185 has no CHG pin**. Status is two open-drain pins, and ILIM and
  VSET are one pin programmed by one resistor.
- The BQ25185's **TS/MR pin cannot float**. Left open, the internal clamp reads
  as a temperature fault and the charger refuses to charge. It needs 10k to
  ground, or a real NTC.
- On the **MAX17048, CELL is not internally connected** -- VDD is the sense
  input. CELL belongs to the 2-cell MAX17049.
- The **ESD array is a USON-10**, not a SOT-23-6.

## Things to check before fab

The full list lives in **`docs/before-layout.md`**. As of 22 September 2026
every parts question on it is closed: the slide switch is a C&K JS102011SAQN,
the USB-C receptacle a GCT USB4105-GF-A, `L2` a Bourns SRN4018-470M, and `U4`'s
exposed pad turned out not to need the drawing. What is left is three things
only a meter and a real panel can settle, and one DC-table read on the fuel
gauge's I²C levels.

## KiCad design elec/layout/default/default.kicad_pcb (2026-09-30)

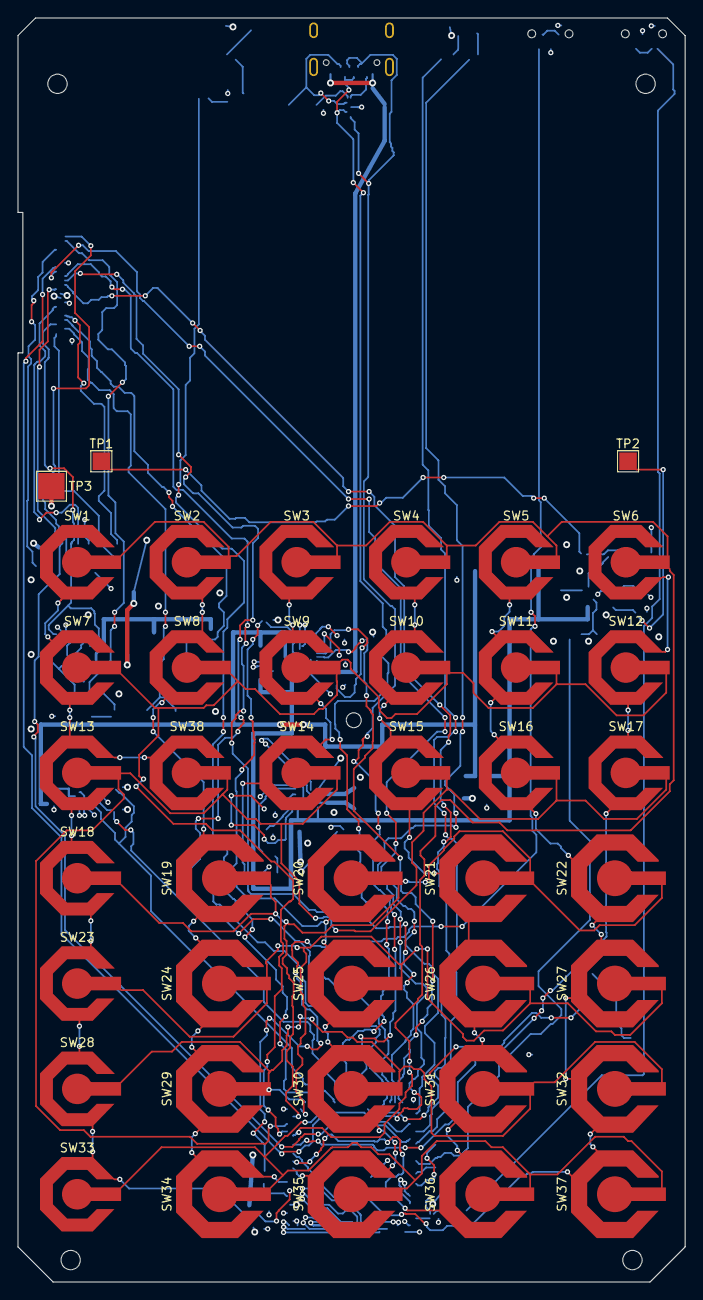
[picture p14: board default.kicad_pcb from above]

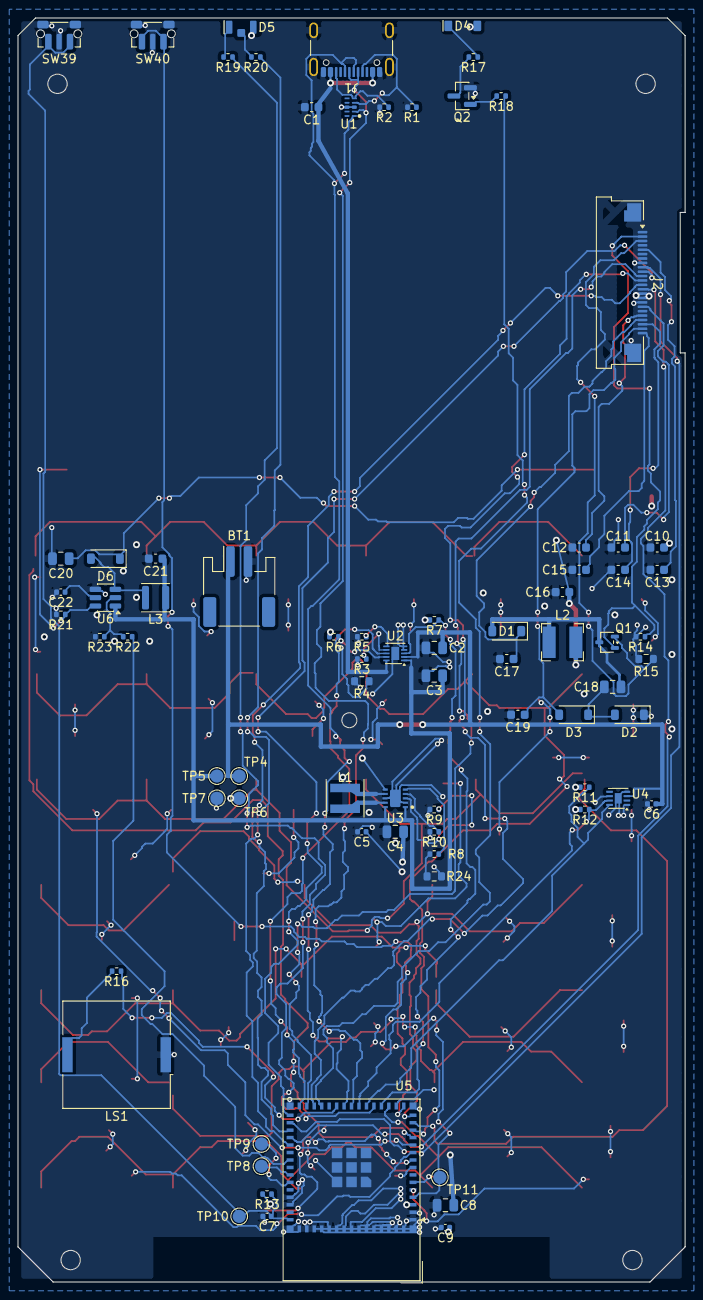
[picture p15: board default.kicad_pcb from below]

Board: 4 copper layers, 76.0 x 144.0 mm, 118 parts (77 on the bottom side), 72 nets.

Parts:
BT1: ?; JST_PH_S2B-PH-SM4-TB_1x02-1MP_P2.00mm_Horizontal
C1, C10, C11, C12, C13, C14, C15, C16, C17, C19, C21: ?; C_0603_1608Metric
C2, C3, C4, C8, C18, C20: ?; C_0805_2012Metric
C5, C6, C7, C9, C22: ?; C_0402_1005Metric
D1, D2, D3, D6: ?; D_SOD-123
D4: ?; Vishay_VSMB2943SLX01_SideView
D5: ?; LiteOn_LTST-S326_BiColor_RA
J1: ?; USB_C_Receptacle_GCT_USB4105-xx-A_16P_TopMnt_Horizontal
J2: ?; Amphenol_F32Q-1A7x1-11024_1x24-1MP_P0.5mm_Horizontal
L1: ?; L_Coilcraft_XxL4020
L2: ?; L_Bourns-SRN4018
L3: ?; L_APV_ANR3015
LS1: ?; Buzzer_Murata_PKLCS1212E
Q1: ?; SOT-323_SC-70
Q2: ?; SOT-23
R1, R2, R3, R5, R6, R7, R8, R9, R10, R11, R12, R13, R14, R16, R17, R18, R19, R20, R21, R22, R23: ?; R_0402_1005Metric
R4, R15, R24: ?; R_0603_1608Metric
SW1, SW2, SW3, SW4, SW5, SW6, SW7, SW8, SW9, SW10, SW11, SW12, SW13, SW14, SW15, SW16, SW17, SW18, SW23, SW28, SW33, SW38: ?; Dome_4Leg_8.5mm
SW19, SW20, SW21, SW22, SW24, SW25, SW26, SW27, SW29, SW30, SW31, SW32, SW34, SW35, SW36, SW37: ?; Dome_4Leg_10mm
SW39, SW40: ?; Alps_SKRTLAE010_SidePush
TP1, TP2: ?; TestPoint_Pad_2.0x2.0mm
TP3: ?; TestPoint_Pad_3.0x3.0mm
TP4, TP5, TP6, TP7, TP8, TP9, TP10, TP11: ?; TestPoint_Pad_D1.5mm
U1: ?; TI_DQA0010A_USON-10_2.5x1mm_P0.5mm
U2: ?; Texas_DSQ0010A_WSON-10-1EP_2x2mm_P0.4mm_EP0.9x1.5mm
U3: ?; TI_DSK0010A_WSON-10-1EP_2.5x2.5mm_P0.5mm_EP2x1.2mm
U4: ?; TDFN-8-1EP_2x2mm_P0.5mm_EP0.8x1.2mm
U5: ?; ESP32-S2-MINI-1
U6: ?; SOT-23-6

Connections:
bat: BT1.1, C2.1, C6.1, TP4.1, U2.2, U4.3
boot: SW40.1, TP11.1, U5.4
buzzer: R16.1, U5.25
cathode: D4.1, R17.1
cc1: J1.A5, R1.1, U1.4
cc2: J1.B5, R2.1, U1.5
cfg1: R9.1, U3.3
cfg2: R10.1, U3.4
cfg3: R8.1, U3.5
cfg3_mid: R8.2, R24.1
chg_stat: R6.1, U2.9, U5.30
chg_stat2: R7.1, U2.3, U5.19
col0: SW1.1, SW7.1, SW13.1, SW18.1, SW23.1, SW28.1, SW33.1, SW38.1, U5.5
col1: SW2.1, SW8.1, SW19.1, SW24.1, SW29.1, SW34.1, U5.6
col2: SW3.1, SW9.1, SW14.1, SW20.1, SW25.1, SW30.1, SW35.1, U5.8
col3: SW4.1, SW10.1, SW15.1, SW21.1, SW26.1, SW31.1, SW36.1, U5.9
col4: SW5.1, SW11.1, SW16.1, SW22.1, SW27.1, SW32.1, SW37.1, U5.10
col5: SW6.1, SW12.1, SW17.1, U5.11
comp: C22.1, U6.5
ctrl: R22.2, R23.1, U6.2
display-sw: C18.1, D1.2, L2.2, Q1.3
drain: Q2.3, R17.2
en: C7.1, R13.1, SW39.1, TP10.1, U5.45
epd_busy: J2.9, U5.32
epd_cs: J2.12, U5.28
epd_dc: J2.11, U5.29
epd_mosi: J2.14, U5.34
epd_rst: J2.10, U5.31
epd_sck: J2.13, U5.33
fb: R21.1, TP2.1, U6.6
frontlight-sw: D6.2, L3.2, U6.3
frontlight_pwm: R22.1, U5.37
gate: Q2.1, R18.2
gdr: J2.2, Q1.1, R14.1
gnd: BT1.2, C1.2, C2.2, C3.2, C4.2, C5.2, C6.2, C7.2, C8.2, C9.2, C10.2, C11.2, C12.2, C13.2, C14.2, C15.2, C16.2, C17.2, C19.2, C20.2, C21.2, C22.2, D2.1, J1.A1, J1.A12, J1.B1, J1.B12, J1.SH, J2.8, J2.17, J2.MP, LS1.1, Q2.2, R1.2, R2.2, R3.2, R4.2, R5.2, R9.2, R10.2, R14.2, R15.2, R21.2, R23.2, R24.2, SW39.2, SW39.MP, SW40.2, SW40.MP, TP3.1, TP7.1, U1.3, U1.8, U2.4, U2.5, U2.11, U3.2, U3.8, U3.11, U4.1, U4.4, U4.6, U4.9, U5.1, U5.2, U5.42, U5.43, U5.46, U5.47, U5.48, U5.49, U5.50, U5.51, U5.52, U5.53, U5.54, U5.55, U5.56, U5.57, U5.58, U5.59, U5.60, U5.61, U5.62, U5.63, U5.64, U5.65, U6.4
i2c_scl: R12.1, U4.7, U5.22
i2c_sda: R11.1, U4.8, U5.21
ilim_vset: R3.1, U2.7
ir_led: R18.1, U5.27
iset: R4.1, U2.8
led_green: R20.1, U5.35
led_red: R19.1, U5.20
lx1: L1.1, U3.9
lx2: L1.2, U3.7
prevgh: C17.1, D1.1, J2.21
prevgl: C19.1, D3.2, J2.23
pump: C18.2, D2.2, D3.1
red: D5.3, R19.2
rese: J2.3, Q1.2, R15.1
row0: SW1.2, SW2.2, SW3.2, SW4.2, SW5.2, SW6.2, U5.12
row1: SW7.2, SW8.2, SW9.2, SW10.2, SW11.2, SW12.2, U5.13
row2: SW13.2, SW14.2, SW15.2, SW16.2, SW17.2, SW38.2, U5.14
row3: SW18.2, SW19.2, SW20.2, SW21.2, SW22.2, U5.15
row4: SW23.2, SW24.2, SW25.2, SW26.2, SW27.2, U5.16
row5: SW28.2, SW29.2, SW30.2, SW31.2, SW32.2, U5.17
row6: SW33.2, SW34.2, SW35.2, SW36.2, SW37.2, U5.18
sounder: LS1.2, R16.2
sys: C3.1, C21.1, L3.1, TP5.1, U2.1, U3.1, U3.10, U6.1
ts_mr: R5.1, U2.6
uart0_rx: TP9.1, U5.40
uart0_tx: TP8.1, U5.39
usb_dm: J1.A7, J1.B7, U1.2, U5.23
usb_dp: J1.A6, J1.B6, U1.1, U5.24
v3v3: C4.1, C5.1, C8.1, C9.1, C10.1, C16.1, D4.2, D5.2, J2.15, J2.16, L2.1, R6.2, R7.2, R11.2, R12.2, R13.2, TP6.1, U3.6, U5.3
vbus: C1.1, J1.A4, J1.A9, J1.B4, J1.B9, U2.10
vcom: C15.1, J2.24
vdd: C11.1, J2.18
vled: C20.1, D6.1, TP1.1
vsh1: C12.1, J2.20
vsh2: C13.1, J2.5
vsl: C14.1, J2.22
ygreen: D5.1, R20.2

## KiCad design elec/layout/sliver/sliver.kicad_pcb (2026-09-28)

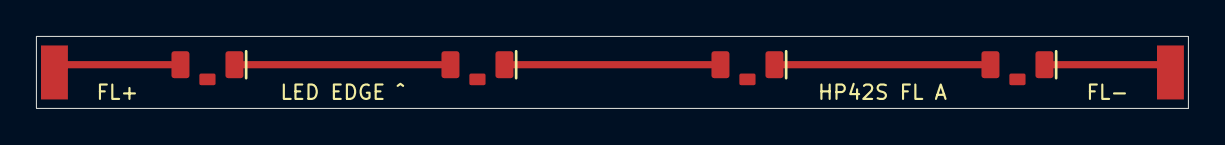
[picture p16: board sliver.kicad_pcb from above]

Board: 2 copper layers, 64.0 x 4.0 mm, 6 parts (0 on the bottom side), 5 nets.

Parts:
D1, D2, D3, D4: 599-2Q01-147F; Dialight_599_White_1208_RA
TP1: FL+; Frontlight_SliverWirePad
TP2: FL-; Frontlight_SliverWirePad

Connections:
fb: D4.1, TP2.1
n1: D1.1, D2.2
n2: D2.1, D3.2
n3: D3.1, D4.2
vled: D1.2, TP1.1

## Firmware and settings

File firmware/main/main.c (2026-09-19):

// main.c -- board bring-up for the HP-42S clone.
//
// This is NOT the calculator. It is the thing you flash onto the first board
// to find out whether the board works: it draws a test pattern on the panel,
// prints every key you press, and then proves the deep-sleep wake path by
// going to sleep and coming back on a keystroke.
//
// Plus42 goes on top of this. Its core is portable C++ that wants a shell
// underneath it, and the shell is what these files are: a panel to draw on, a
// keyboard to read, and a way to sleep. See firmware/README.md.

#include <stdio.h>

#include "board.h"
#include "epd.h"
#include "keypad.h"

#include "esp_log.h"
#include "esp_sleep.h"
#include "freertos/FreeRTOS.h"
#include "freertos/task.h"

static const char *TAG = "hp42s";

// Sleep after this long with nobody pressing anything. The real firmware will
// want a minute or two; ten seconds makes the wake path easy to test.
#define IDLE_SLEEP_MS 10000

static void draw_test_pattern(int last_key)
{
    epd_clear(true);

    // A frame, so it is obvious at a glance whether the whole panel is alive
    // and which way round it is.
    epd_fill_rect(0, 0, EPD_W, 2, true);
    epd_fill_rect(0, EPD_H - 2, EPD_W, 2, true);
    epd_fill_rect(0, 0, 2, EPD_H, true);
    epd_fill_rect(EPD_W - 2, 0, 2, EPD_H, true);

    // A solid block in the top left corner only. If the panel comes up
    // mirrored or rotated this is the thing that shows it.
    epd_fill_rect(8, 8, 24, 12, true);

    // A bar chart of the last key number, one bar per key, so a keypress is
    // visible on the glass without a font.
    for (int i = 0; i < KEY_MAX; i++) {
        int x = 8 + i * 7;
        int h = (i + 1 == last_key) ? 60 : 12;
        epd_fill_rect(x, EPD_H - 12 - h, 5, h, true);
    }
}

void plus42_start(void);
void bid_selftest(void);

void app_main(void)
{
    bid_selftest();
    plus42_start();

    // Read this before anything re-drives the matrix: it is latched by the
    // wake and the rows have to stay as sleep left them to decode it.
    int woke_on = keypad_wake_key();

    keypad_init();
    gpio_set_direction(PIN_LED_RED, GPIO_MODE_OUTPUT);
    gpio_set_direction(PIN_LED_GREEN, GPIO_MODE_OUTPUT);
    gpio_set_level(PIN_LED_RED, LED_OFF);
    gpio_set_level(PIN_LED_GREEN, LED_ON);

    ESP_ERROR_CHECK(epd_init());

    if (woke_on != KEY_NONE)
        ESP_LOGI(TAG, "woke on key %d", woke_on);
    else
        ESP_LOGI(TAG, "cold start");

    draw_test_pattern(woke_on);
    ESP_ERROR_CHECK(epd_update_full());

    int idle_ms = 0;
    int last_key = woke_on;

    while (1) {
        int k = keypad_scan();
        if (k != KEY_NONE) {
            ESP_LOGI(TAG, "key %d", k);
            gpio_set_level(PIN_LED_RED, LED_ON);
            last_key = k;
            draw_test_pattern(last_key);
            epd_update_partial();
            gpio_set_level(PIN_LED_RED, LED_OFF);
            keypad_wait_release();
            idle_ms = 0;
            continue;
        }

        vTaskDelay(pdMS_TO_TICKS(20));
        idle_ms += 20;

        if (idle_ms >= IDLE_SLEEP_MS) {
            ESP_LOGI(TAG, "idle, going to sleep -- press any key");
            gpio_set_level(PIN_LED_GREEN, LED_OFF);
            epd_sleep();
            keypad_arm_wake();
            esp_deep_sleep_start();
        }
    }
}

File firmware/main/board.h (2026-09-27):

// board.h -- every pin on the HP-42S clone, in one place.
//
// These are not choices to make here. They come out of elec/src/hp42s.ato and
// are fixed by the schematic; docs/connections.md is the readable version of
// the same table. If a pin moves on the board it moves here, and nowhere else.
#pragma once

#include "driver/gpio.h"

// --- keypad: 6 columns x 7 rows, 37 keys, no diodes ------------------------
// Rows are driven, columns are read. Columns sit on RTC-capable GPIOs so they
// can wake the chip from deep sleep through ext1 with no scanner and no
// standing current; that is most of the battery life.
#define KP_COLS 6
#define KP_ROWS 7

static const gpio_num_t kp_col[KP_COLS] = {
    GPIO_NUM_1, GPIO_NUM_2, GPIO_NUM_4, GPIO_NUM_5, GPIO_NUM_6, GPIO_NUM_7,
};
static const gpio_num_t kp_row[KP_ROWS] = {
    GPIO_NUM_8,  GPIO_NUM_9,  GPIO_NUM_10, GPIO_NUM_11,
    GPIO_NUM_12, GPIO_NUM_13, GPIO_NUM_14,
};

// --- e-paper panel, GDEY0266T90 / SSD1680 ----------------------------------
#ifndef HP42S_WOKWI
#define EPD_CS   GPIO_NUM_33
#define EPD_DC   GPIO_NUM_34
#else
// The Wokwi simulation runs on an ESP32-S3-DevKitC-1, whose headers do not
// bring out GPIO 33 and 34 (the module uses them for octal PSRAM). Both are
// free pins on the real board, so the simulation borrows 40 and 42 instead.
// sim/wokwi/ builds with HP42S_WOKWI defined; nothing else ever should.
#define EPD_CS   GPIO_NUM_40
#define EPD_DC   GPIO_NUM_42
#endif
#define EPD_RST  GPIO_NUM_35
#define EPD_BUSY GPIO_NUM_36
#define EPD_SCK  GPIO_NUM_37
#define EPD_MOSI GPIO_NUM_38

// --- everything else -------------------------------------------------------
#define PIN_SOUNDER   GPIO_NUM_21   // 1k in series into the piezo element
#define PIN_IR_LED    GPIO_NUM_47   // FET gate, HP-82240 printing
#define PIN_LED_RED   GPIO_NUM_16   // common anode: LOW lights it
#define PIN_LED_GREEN GPIO_NUM_39
#define PIN_I2C_SDA   GPIO_NUM_17   // MAX17048 fuel gauge, 4k7 pull-ups
#define PIN_I2C_SCL   GPIO_NUM_18
#define PIN_CHG_STAT1 GPIO_NUM_48   // BQ25185, open drain, 100k pull-ups
#define PIN_CHG_STAT2 GPIO_NUM_15
#define PIN_BOOT      GPIO_NUM_0    // BOOT button and its test pad

// The status LED is common anode, so it lights on a LOW.
#define LED_ON  0
#define LED_OFF 1

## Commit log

2026-09-18 Start the HP-42S clone repo: wiring as atopile source
    The design so far lived in one document and two generated footprints. This
    puts it in a form a compiler checks.
    elec/src/*.ato is the whole board as atopile source: 37 dome keys on a 6x7
    matrix, the USB-C / BQ25185 / TPS63900 / MAX17048 power chain, and the
    ESP32-S3-MINI-1-N8 GPIO map. `ato build` turns it into a KiCad netlist and a
    BOM -- 81 components, 48 nets, no errors. atopile does not place or route, so
    layout still happens in KiCad, in elec/layout/.
    Two deliberate limits, both stated in the source:
    - Every IC declares its pins by NAME, not number. The netlist is therefore
    correct about what connects to what and silent about wh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
2026-09-18 Use real KiCad footprint names instead of invented ones
    Importing the netlist failed on all 81 components: "footprint not found in
    any libraries in the footprint library table". Two causes, both mine.
    Every footprint name was written from memory and unqualified, so atopile
    prefixed them `lib:` -- a library nickname that exists nowhere. Names like
    `R_0402_1005Metric` happen to be right, but `WSON-10-1EP_2x2mm` and
    `FPC_24_0.5mm_BottomContact` are not names KiCad has ever used.
    Each one is now library-qualified and looked up in KiCad's own footprint
    library rather than recalled. That leaves three parts KiCad genuinely has no
    footprint for:
    - TPS63900: KiCad's only VQFN-12 is 4 x 4 mm, this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
2026-09-19 Use the measured key grid instead of a uniform pitch
    Barnaby measured a real HP-42S. The row pitch was right at 12.0 mm. The
    columns were not: there are two grids, not one.
    Rows 1-3 run six columns at 12.5 mm with 7.5 mm caps. Rows 4-7 keep the left
    column on the same 8.75 mm centre, still a 7.5 mm cap, then switch to four
    numeric columns at 15.0 mm with 10 mm caps. The old uniform 11.8 mm grid put
    every numeric key in the wrong place and squeezed the function rows.
    Dome choice now follows the cap rather than the row, which moves UP, DOWN,
    SHIFT and EXIT to the 8.5 mm dome: they are narrow keys beside the numeric
    block, not part of it. 22 small domes and 16 large, from 18 and 20.
    The keyb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
2026-09-19 Add the e-paper drive circuit, and USB-C plus power and reset on the top edge
    The panel had a connector and a 3.3 V rail and nothing else. An SSD1680 makes
    its own +22 V and -20 V gate rails but has no inductor or switch on the glass,
    so it reaches out through GDR and RESE for both. That network -- one boost
    diode for the positive rail, a charge pump off the same switching node for the
    negative one, and ten 25 V capacitors -- is now in elec/src/display.ato, taken
    from Good Display's GDEY0266T90 specification 24.12.03 page 28 rather than
    from a generic SSD1680 example. The FPC connector now carries the real 24-pin
    numbering.
    USB-C, a side-actuated power slider and a side-actuated reset butto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
2026-09-19 Give the MCU, the ESD array and the IR LED real pin numbers; add the PCB process guide
    KiCad matches netlist pins to footprint pads by name, so a pin called IO33
    against a footprint whose pads are numbered 1..65 imports silently
    unconnected. The ESP32 was the one that mattered. Its numbering here comes
    from KiCad's own ESP32-S3-MINI-1 symbol, not from memory, and that symbol also
    settles the footprint question: it points at RF_Module:ESP32-S2-MINI-1 itself,
    because the MINI-1 package is shared across the family. All 24 ground pads are
    now tied.
    Two things that check turned up. The ESD array is a USON-10 2.5 x 1.0 mm part,
    not the SOT-23-6 it had been given -- that footprint was wrong, not j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
2026-09-19 Finish the charger, regulator and gauge from their datasheets; add BOOT, a status LED and a side-emitting IR window
    Barnaby supplied the three datasheets that were blocking this. Reading them
    properly found five things that were wrong rather than merely unmapped, and
    any one of them would have cost a board spin:
    - The TPS63900 has no feedback divider. Output voltage is set by resistors
    on CFG1/CFG2/CFG3, none of which may be left open. CFG3 = 16.2k gives
    3.3 V on VO(1), which SEL low selects. It is also a 2.5 x 2.5 mm WSON-10,
    not the VQFN-12 claimed here; the land pattern is now generated from TI
    drawing 4218903/C by tools/gen_ic_footprints.py.
    - The BQ25185 has no CHG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
2026-09-19 Give the IR emitter the VSMB2943SLX01's real land pattern
    Barnaby sent the datasheet for the part I had flagged as unconfirmed. It is
    side-looking, as needed, but it is 2.3 x 2.55 x 2.3 mm rather than the 1.6 x
    0.6 mm Kingbright outline that was standing in for it: two 0.9 x 1.2 mm pads
    4.2 mm across the outsides.
    Generate that pattern from Vishay's own IPC 7351 proposal (document 83479
    rev 1.2), move the part 0.4 mm further into the board so the dome tip still
    stops 0.22 mm short of the edge, and record the number the case needs: the
    optical axis sits 1.2 mm above the face of the board it is soldered to, which
    is the back.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
2026-09-19 Get Plus42 building for the ESP32-S3
    Barnaby sent the Plus42 1.3.15 source, so the core is no longer a hole in the
    firmware. It compiles for xtensa: all 26 files of Thomas Okken's portable core
    and all 237 of Intel's decimal library, with no source changes to either.
    main/shell.cc is the platform layer. The display blitter is real and goes
    through epd_pixel(); milliseconds, random seed and logging are real; the
    beeper, printer, clock and power-down are stubs for now. Keys are not yet fed
    to core_keydown() and nothing saves state, so this links and starts rather
    than calculates.
    Measured at -Os with the whole core linked: 2.85 MB of flash and 113 KB of
    RAM, which needs a 4 MB app partition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
    [partitions.csv]
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2026-09-23 Place the board by writing the file, not through KiCad's API
    place_keypad.py asks pcbnew to put footprints at absolute millimetre
    positions. Under KiCad 10.0 that does not work: the first run put all 45
    footprints it touched 414.5 mm from where it asked, a second run put them
    345.0 mm out, and the board outline and comment rectangles drawn through the
    same API in the same run landed exactly right. Reading a position back returns
    the value that was asked for, so neither the script nor fix_offset.py could
    tell that anything had gone wrong.
    The relative geometry was never in question -- one clean translation of the
    whole block, every rotation correct -- so this keeps the arithmetic and
    changes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
    [default.kicad_pcb]
2026-09-23 Push the six top-edge parts out towards the case wall
    Barnaby pointed out that the slider knob, the USB-C mouth and the rest need
    to reach past the board edge to be usable through the case. They were not:
    the USB-C mouth sat exactly on the outline and the slider knob 0.80 mm past
    it, against 2.00 mm from the board edge to the case's outer surface (0.80 mm
    of assembly clearance plus a 1.20 mm wall).
    Each part is now as far out as its own pads allow, measured from the library
    footprints rather than estimated:
    slider 2.30 mm past the edge, set to stand 0.3 mm proud of the case
    USB-C 1.20 mm, stopped by its through-hole shield legs
    status LED 1.12 mm
    IR emitter 1.08 mm
    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
    [default.kicad_pcb]
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2026-09-23 layout: after the offset correction
    [default.kicad_pcb]
2026-09-23 layout: place every part to the placement rules, and put the pads back
    Two faults and a rework.
    The pads. Every footprint on the board had its pads about 1.1 metres from
    the footprint they belong to, while its silkscreen, courtyard and fab
    outline were all in the right place. All 119 shared the same offset --
    (-702.5, -880.5) at 0 degrees, (1212.5, 1211.5) for the four parts rotated
    180, (1301.0, -1123.0) for the flipped FPC -- so every pad on the board
    landed in one pile off the side of it. It was there from the first save,
    before any placement script wrote to the file, so it came in with the
    netlist import. KiCad's format is explicit that a footprint's children are
    measured from the footp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
    [default.kicad_pcb]
2026-09-23 layout: correct the placement offset
    [default.kicad_pcb]
2026-09-23 layout: turn the back-side parts over in the file, not in KiCad
    The Scripting Console step did not take: 118 of 119 parts were still on
    F.Cu after it. Rather than debug it blind, place_board.py now sets the side
    itself, so the whole repair is three terminal commands and nothing goes
    through the API.
    A flipped footprint is not the same footprint with B.* layer names: KiCad
    mirrors every coordinate inside it in y and marks its text as mirrored.
    place_board.py does that; the 3D model block is left alone because KiCad
    places the model from the footprint's side.
    fix_pads.py no longer shifts the pads it finds -- it writes the library
    footprint's own values outright, which is what a pad's (at x y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
    [default.kicad_pcb]
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2026-09-23 layout: turn U5 the right way up, and derive its keepout from the module
    Barnaby noticed the antenna was pointing into the keyboard. He was right.
    U5 was at 180 degrees while it was on the front, which put the antenna at
    the bottom edge. Moving it to the back mirrors it, and that reverses the
    antenna end, so 180 now points the antenna up the board. It is 0 degrees
    now, and the keepout lands at Y 138.75..158.25 -- hanging off the bottom
    edge, where it belongs.
    Everything around the module mirrors with it: 3V3 and BOOT are on the left
    now, EN and the UART on the right, so C7, C8, C9, R14 and TP8 to TP11 have
    swapped sides to stay at their pins.
    check_placement.py no longer has the keepout re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
    [default.kicad_pcb]
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2026-09-23 layout: put the antenna rule area where the antenna is
    Step 8's six copper zones are right: gnd on B.Cu and In1.Cu, v3v3 over the
    whole of In2.Cu at priority 2, and the three gnd rectangles under the
    switching nodes at priorities 3 to 5 so they win against it.
    The rule area was wrong in two ways. It was on In2.Cu alone rather than all
    four copper layers, so the front, In1 and back pours would still have filled
    under the antenna. And it was at X 29.5..46.5, Y 123..128.5, which is in the
    middle of the keyboard -- the antenna overhangs the bottom edge at
    X 15.30..60.70 from Y 138.75 down.
    Also allows pads inside it. The bottom row of key domes reaches Y 139.00,
    0.25 mm in, and there is nowher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
    [default.kicad_pcb]
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2026-09-23 elec: vendor 3D models, and the two things they caught
    Barnaby found real vendor STEP for all seven footprints we drew ourselves.
    They replace the envelopes I generated this evening, which are gone.
    The originals are in elec/footprints/vendor-3d exactly as they came.
    tools/place_3d_models.py turns and moves each one onto its footprint origin
    and writes elec/footprints/hp42s.3dshapes, which is what the footprints
    point at. Not one of them arrived in KiCad's convention:
    Keystone 5154TR / 5134TR dome axis along Y, needed standing up
    Alps SKRTLA already right; board face was at z -1.65
    Dialight 599 lies on its side; solders on its y = 1.0 face
    Vishay VSMB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
    [Alps-SKRTLA.step, Dialight-599-0Q70-247F.step, TI-DQA0010B.step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]
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2026-09-24 Centre the USB-C, respace the top edge on equal gaps, square the pours
    J1 goes on the board's centreline at x = 38.00, and every adjacent pair
    along the top edge is now 5.00 mm courtyard to courtyard rather than the
    hand-chosen centres it had. Equal gaps, not equal centres: these five
    parts run from 4.50 to 10.64 mm wide, so equal centres read as crowded at
    the USB-C and empty at the status LED.
    The two indicators straddle the connector, and the status LED shares its
    side with BOOT and RESET. New x: D4 25.33, J1 38.00, D5 50.57, SW41
    60.65, SW40 71.31. The nine support parts behind them moved with them and
    are back on their grids (Q2 to 25.4 to stay on the 1.27 mm IC grid, which
    pushed R19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
    [default.kicad_pcb]
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2026-09-24 Stop a designator renumber from silently scrambling the placement
    The netlist re-import is correct. The tables in place_board.py were not.
    Deleting the power slider also deleted the 1 M that held EN down, and
    atopile hands out designators in source order, so every resistor after it
    moved down a number: old R12 became R11, on to R24 becoming R23. The
    re-import renames them in place, as tstamp linking should. But the
    placement tables are keyed on designators, so the entry written for R19
    was pointing at the part that used to be R20, and a run of place_board.py
    moved thirteen resistors to each other's positions.
    Nothing caught it. The board still had the right footprint count,
    fix_pads.py rep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
    [default.kicad_pcb]
2026-09-24 Put a via keepout over every dome site
    A metal dome is a shallow disc that has to sit flat on its ring. A via
    inside that ring lifts it, and a lifted dome either never closes or closes
    at the wrong force. Nothing in the board said so: to KiCad a dome site is
    two copper shapes and some silkscreen, and a router asked to find its way
    out of a 6x7 matrix will drop a via in the middle of one without
    hesitating. Step 9a hands Freerouting the keypad matrix deliberately, so
    the rule has to exist in the board rather than in a walkthrough.
    tools/dome_keepouts.py writes one rule area per dome, on all four copper
    layers, with the dome's own courtyard as its outline: tracks allowed, vias
    not allowed, pa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
    [default.kicad_pcb]
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2026-09-25 Route steps 9.1 and 9.2, and find four things by doing it
    The two switching loops and all of the power distribution -- vbus, sys, bat
    and v3v3 -- written into the board by tools/route_power.py, which validates
    every route and refuses to write if anything fails: an end that does not land
    in a pad of its own net, a track within 0.2 mm of a foreign pad or track, a
    via inside a dome keepout or off the board. Real rectangle-to-capsule
    distance, because most of these routes pass within half a millimetre of
    something.
    66 segments and 23 vias. L1 is turned a quarter turn: with its pads along x,
    both of U3's switch pins faced the same pad and lx2 had to go 12 mm round the
    inductor's body for a node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
    [default.kicad_pcb]
2026-09-26 Fix what KiCad's DRC found in the power routing
    Barnaby ran the design rule check over steps 9.1 and 9.2 and got 102
    violations. Not one of them was a clearance violation, which is the
    reassuring part: the script measures the same distances KiCad does. What it
    got wrong, it got wrong by not knowing something was there.
    A 3.3 V via beside U3 pin 6 was sitting inside SW14's row2 pad. A KiCad
    custom pad is its (size w h) rectangle *unioned with* its primitives, and
    this script was reading only the rectangle. The dome's centre pad is a
    3.48 mm square plus a tab reaching 5.0002 mm east of it, so the tab was
    invisible and the spot looked like bare board. route_power.py now builds a
    pad out of bot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
    [default.kicad_pcb]
2026-09-26 Actually fix the dome pad the last commit only claimed to fix
    c152bd1 taught route_power.py that a KiCad custom pad is its rectangle
    unioned with its primitives, and then read those primitives with a regex
    shaped like the library's one-line formatting. The board file writes the
    same primitive over six indented lines, so on the board it matched nothing,
    every pad fell back to its rectangle, and the 3.3 V via beside U3 pin 6 was
    still sitting inside SW14's row2 tab. Primitives are read with balanced
    brackets now, and an unrecognised primitive is a hard error rather than a
    silent zero shapes.
    That exposed two more of the same kind of mistake, both of which had been
    hidden behind the first:
    A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
    [default.kicad_pcb]
2026-09-27 Stitch the three inner ground islands to the plane
    Step 8.3b carves three ground islands out of the 3.3 V plane on In2.Cu so the
    switching nodes have a return directly underneath them. None of them had a
    via, which is what KiCad's three isolated_copper errors were saying: copper on
    an inner layer can only be reached by a via, and an island of metal with no
    connection is not a ground.
    New tool, stitch_zones.py, places plain gnd vias inside each island. No track
    is needed -- every pour of the net fills up to a via of its own net and bonds
    to it -- and a through via passes through the B.Cu pour and the In1.Cu plane
    on the way, so one via ties all three layers. Roughly one via per 30 mm2,
    chose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
    [default.kicad_pcb]
2026-09-27 Start the Wokwi simulation: SSD1680 chip and keypad test firmware
    The SSD1680 custom chip decodes the command set epd.c uses, keeps the RAM
    and its address counters, models BUSY, reset and deep sleep, and warns
    about the mistakes that leave a real panel blank. It builds to WASM here.
    The test firmware links keypad.c and epd.c unmodified. HP42S_WOKWI moves
    the panel's CS and DC to GPIO 40 and 42, since the DevKitC-1 does not
    bring out 33 and 34. The diagram, wokwi.toml and scenario are still to
    do; sim/wokwi/README.md lists them.
    Claude-Session: https://claude.ai/code/session_016G6D9KuQ66qC84AiA6e4kh
    [board.h]
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2026-09-27 Route steps 9.3 to 9.5: every signal net, plus ground tails
    tools/route_signals.py now routes all 63 non-power nets (4065 mm, 271 vias)
    and, inside the same negotiated loop, gives each gnd pad the new tracks would
    cut off from the B.Cu pour a tail and via of its own (67 tails). The exact
    geometry audit is clean and check_pour.py finds no stranded gnd pad.
    The walkthrough's "one via per net" claim for the matrix is corrected: rows
    cross every column, so the matrix takes 107 vias, not 13.
    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
    [default.kicad_pcb]
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2026-09-27 3D models for the last six parts, plus the cell and the panel
    Barnaby's vendor STEP for U5 (ESP32-S3-MINI-1-N8), U4 (MAX17048G+T10),
    L1 (XFL4020-222MEC), LS1 (PKLCS1212E4001-R1), BT1 (JST S2B-PH-SM4-TB) and
    J2 (Amphenol F32Q-1A7H1-11024), turned and seated on KiCad's footprints by
    place_3d_models.py; every one lands inside its courtyard.
    tools/mech_models.py draws the LiPo cell and the panel glass, active area
    and folded flex tail from docs/display-mounting.md, hung off TP3, so the
    board's STEP export carries them into the case model.
    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
    [ADI-MAX17048GT10.step, Amphenol-F32Q-1A7H1-11024.step, Coilcraft-XFL4020-222MEC.step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]
2026-09-28 Mounting holes A-D and G, and the board rerouted round them
    tools/mounting.py writes five unplated holes as Edge.Cuts circles, each in a
    copper-free rule area: M2 at the four corners, mirrored about the case
    centreline and level in pairs, and an M1.6 at the centre of the keypad.
    bat now dips 2.5 mm south round G. Every signal is rerouted; the audit is
    clean and check_pour.py finds every gnd pad reaching the plane.
    Fixes a router bug the rerun exposed: its own gnd tails from the previous run
    stood in for the plane while routing and were then deleted on write, which
    stranded 72 gnd pads. They are now treated as its own copper throughout, and
    the route cache is keyed on the whole script.
    Co-A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
    [default.kicad_pcb]
2026-09-28 Route C18 into display-sw (Q1 drain); reroute signals round it
    The charge-pump cap's switch-node pad was never connected: route_power
    owned display-sw but only routed Q1, L2 and D1, and route_signals skips
    nets that already carry someone else's copper.
    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
    [default.kicad_pcb]
2026-09-28 Fix the nine unconnected items from Barnaby's DRC
    - Pads are read as their declared shape (circle, oval, roundrect), not
    their bounding box: TP10 and TP11's tracks ended in the corners of
    squares that are really circles.
    - 3.3 V plane vias keep out of the step 8.3b ground islands on In2.Cu;
    five had landed inside them and reached no 3.3 V. L2's input hops the
    display-sw spine on F.Cu into C16 and shares its via.
    - TP3, the one F.Cu-only ground pad, gets a via.
    - route_signals merges new vias that sit on or beside one of their own
    net (eleven were stacked at one spot).
    - check_pour.py now also checks every 3.3 V plane via lands in the plane.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
    [default.kicad_pcb]
2026-09-28 Round pads really are round now; draw the frontlight sliver
    The pad-shape fix in e8751d7 never ran: the header match was anchored
    at the start of a block that begins with a tab, so every pad still read
    as its bounding box and TP9/TP10/TP11 stayed unconnected in KiCad. Now
    circles, ovals and roundrects are read as themselves; power and signals
    rerouted. tools/check_ends.py checks every track end lands on its net.
    The sliver is its own board, elec/layout/sliver/, written by
    tools/make_sliver.py: 64 x 4 mm, 1.0 mm, four LEDs flush with the top
    edge, FL+/FL- wire pads on the overhang. Wire pads added to
    FrontlightStrip and the library.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
    [default.kicad_pcb, sliver.kicad_pcb]
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2026-09-28 Place R24 and the resized parts; reroute
    R24 (the 1.2k half of CFG3) sits under R8, turned 180 so cfg3_mid is a
    2 mm stub; the SYS loop round U3's CFG resistors drops 2.2 mm to make room.
    R15 (now 0603) moves 0.635 west to clear Q1, C18 (now 0805) 0.635 south to
    clear R15. The re-import renamed one of R8's old ground-tail vias to
    cfg3_mid, which hid the net from route_signals; deleted, then everything
    rerouted: 0 failed, audit clean, every end on copper, every gnd pad on
    the plane, every v3v3 via in the plane, no do-not-place flags.
    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
    [default.kicad_pcb]
2026-09-29 U3: put the TPS63900's lands where TI draws them, and reroute
    TI drawing 4218903/B dimensions the two pad columns (2.3) centre to
    centre -- its extension lines sit on the pads' centrelines -- and the
    generator read it as outer edge to outer edge. So all ten signal lands
    sat 0.3 mm too far in, their inner ends under the package's own 1.2 mm
    thermal pad; the 0.7 mm board thermal land from 87e51e9 only hid it.
    Lands now 0.6 x 0.25 at x +/-1.15 with the full 1.2 x 2.0 thermal pad,
    courtyard +/-1.7. route_power's four U3 pin entries follow; everything
    the plane, every v3v3 via in the plane, placement all clear.
    Co-Authored-By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
    [default.kicad_pcb]
2026-09-29 J2: move 2 mm toward the edge so the FPC tail has slack, and reroute
    The tail ended exactly at the connector's back wall, with no give. J2 now
    sits at X 7.75 (back wall X 8.50), leaving 2 mm of tail as a strain-relief
    loop under the board (1.7 mm at the tail's -0.3 mm tolerance).
    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
    [default.kicad_pcb]
2026-09-30 DRC 30 Sep: keep other nets out of dome mask openings, fix U5 keepout
    - route_signals treats each dome's F.Mask aperture as a block for every net
    but the dome's own; row0 and row3 had cut up to 0.12 mm into SW25's and
    SW30's openings, leaving bare row copper beside a column ring. Rerouted,
    audit extended to check it.
    - U5's own antenna rule area allows pads and footprints, as the step 8.4
    one does: the bottom-row domes reach 0.25 mm into it by design.
    - Domes allow bridged mask apertures between their own pads, which removes
    the by-design solder_mask_bridge noise inside each footprint.
    - U3's pin-1 dot moved off pad 1 after the land fix.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
    [default.kicad_pcb]
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2026-09-30 Board outline: 2 mm chamfers on the top corners, 4 mm on the bottom
    So the board clears the case's inside fillets. Only RESET's mounting pad comes
    near a cut (0.44 mm, against the 0.25 mm edge rule); every check passes.
    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
    [default.kicad_pcb]
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
